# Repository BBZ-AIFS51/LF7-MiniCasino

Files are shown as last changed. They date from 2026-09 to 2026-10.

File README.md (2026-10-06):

<p align="center">
  <picture>
    <source media="(max-width: 600px) and (prefers-color-scheme: dark)" srcset="docs/banner-narrow-dark.svg">
    <source media="(max-width: 600px)" srcset="docs/banner-narrow-light.svg">
    <source media="(prefers-color-scheme: dark)" srcset="docs/banner-dark.svg">
    mini casino: the console with the oled showing the menu, the 4x4 keypad and the rfid tap zone
  </picture>
</p>

a tiny casino on an arduino uno. tap an rfid card, pick black, red or green on the keypad, watch the colours spin on the oled and let the buzzer celebrate. balances live in the uno's eeprom, so the card is just your key.

**[▶ open the 3d model in your browser](https://bbz-aifs51.github.io/LF7-MiniCasino/)**. it plays the game with the real firmware logic, shows every part and wire and has the admin panel built in.

<p align="center">
  <picture>
    <source media="(max-width: 600px) and (prefers-color-scheme: dark)" srcset="docs/how-it-works-narrow-dark.svg">
    <source media="(max-width: 600px)" srcset="docs/how-it-works-narrow-light.svg">
    <source media="(prefers-color-scheme: dark)" srcset="docs/how-it-works-dark.svg">
    how a round works: tap a card, pick a colour, watch the spin, hear the jingle, the balance stays in the eeprom
  </picture>
</p>

## parts

| part | notes |
|---|---|
| arduino uno r3 | atmega328p, usb to the pc, admin protocol at 115200 baud |
| 1.3" oled 128x64 | sh1106 or ssd1306, i2c 0x3c, 4 pins: gnd vcc scl sda |
| rc522 rfid reader | 13.56 mhz, 3.3 v only. any mifare card, fob or ntag works as key |
| 4x4 membrane keypad | 8 pins, no resistors, no gnd. 1 / 2 / 3 bet on black, red, green |
| passive buzzer module + 330 Ω | 3 pins (s, middle, −), plays the jingles |
| half size breadboard, jumpers | 11 female–male, 15 male–male |

## wiring

| part | pin | uno |
|---|---|---|
| oled | gnd / vcc / scl / sda | gnd / 5v / a5 / a4, over the breadboard j2–j5 |
| keypad | 1 / 2 / 3 / 4, columns abcd · 369# · 2580 · 147\* | d3 / d4 / d5 / d6 |
| keypad | 5 / 6 / 7 / 8, rows \*0#d · 789c · 456b · 123a | d7 / d8 / a0 / a1 |
| rc522 | sda / sck / mosi / miso / rst | d10 / d13 / d11 / d12 / d9 |
| rc522 | gnd / 3.3v, irq stays free | gnd / 3.3v, never 5v |
| buzzer | s over 330 Ω, − to the gnd rail | d2 |

keypad pin 1 is the right contact when you look at the keys with the tail down. a2 and a3 are free, d0 and d1 stay free for usb. the breadboard hole by hole is in [UMBAU_OLED.md](UMBAU_OLED.md) and in the picture.

<p align="center">
  <picture>
    <source media="(prefers-color-scheme: dark)" srcset="docs/wiring-dark.svg">
    wiring: uno, breadboard with buzzer and 330 ohm, oled lead in j2 to j5, rc522 and keypad straight to the uno
  </picture>
</p>

<p align="center">
  <picture>
    <source media="(prefers-color-scheme: dark)" srcset="docs/schematic-dark.svg">
    schematic of the mini casino v11
  </picture>
</p>

<p align="center">
  <picture>
    <source media="(prefers-color-scheme: dark)" srcset="docs/pinout-dark.svg">
    uno pinout: which part sits on which pin
  </picture>
</p>

## get it running

1. nothing to install: the oled and rc522 drivers live in the sketch folder.
2. upload `Hardware_Test/Hardware_Test.ino` once to check the oled, the reader and the keypad.
3. open `MiniCasino/MiniCasino.ino`, pick arduino uno and your port, upload.
4. tap a card. new cards get 100 points, then press 1, 2 or 3. a types a new stake, b logs out, c is the volume, d the help.

## the game

* the stake starts at 10 and goes up to 2550 in steps of 10 (key a). black and red pay 2x, green pays 9x. odds are 45 / 45 / 10 %
* a session ends after 60 s without a key press, tap the card again to continue
* up to 31 cards fit into the eeprom, every account keeps two crc protected copies

switches at the top of the sketch: `CASINO_SOUND_MODE` (0 off, 1 passive, 2 active buzzer), `CASINO_EURO` (€ or pkt on the display), `CASINO_OLED_SSD1306` (0 sh1106, 1 ssd1306), `CASINO_SIM` (run without the rc522), `CASINO_NACHLADEN` (refill all accounts once) and `CASINO_EEPROM_LOESCHEN` (wipe everything once).

## extras

* **admin panel**: double click `Panel starten.bat` (or run `python admin/panel.py`) and open http://127.0.0.1:8080. see and edit every balance over usb, ban cards or make one an admin card with unlimited credit. works on a raspberry pi too.
* **no hardware yet?** run `python simulation/build_sim.py` and paste the output into [wokwi](https://wokwi.com). four buttons stand in for the cards. details in [simulation/README.md](simulation/README.md).
* **build check**: `python pruefen.py` compiles for the uno and runs the compile time tests, no upload needed.

## case

a 3d printable console for the whole build, two parts, no supports. stl files, the parametric model and the print notes live in [case/](case/README.md).

**[▶ open the 3d model in your browser](https://bbz-aifs51.github.io/LF7-MiniCasino/)**. the same page lives in the repo as [case/viewer/index.html](case/viewer/index.html) and works offline.

<p align="center">
  case layout: lid top view with oled window, keypad recess, tap zone and grille, plus two sections, in mm
</p>

## more docs (german)

[UMBAU_OLED.md](UMBAU_OLED.md) oled build · [ANLEITUNG.md](ANLEITUNG.md) wiring in detail · [SPIELPLAN_V8.md](SPIELPLAN_V8.md) rules and pins · [SOUND_V9.md](SOUND_V9.md) buzzer · [LOG_ANLEITUNG.md](LOG_ANLEITUNG.md) serial log · [TESTPLAN.md](TESTPLAN.md) test plan

## credits and license

made by **FelixTheDev - Felix Grad** ([felixthedev.com](https://felixthedev.com)) and **derfacn** ([derfacn.com](https://derfacn.com)), lf7 project, bbz aifs51.

licensed under the [Mini Casino Attribution License](LICENSE): you may use, copy and change everything, but every copy, fork or public use has to credit FelixTheDev - Felix Grad and derfacn visibly and link [felixthedev.com](https://felixthedev.com) and [derfacn.com](https://derfacn.com).

 the graphics and the schematic are generated by `docs/make_graphics.py` straight from the firmware and the case model.

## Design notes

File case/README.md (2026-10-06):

# case

a 3d printable console for the V11 build. two parts, a body and a lid, everything else screws, clips or sticks onto them. the lid is tilted by 10°: the oled sits behind a chamfered window right above the keypad, the rfid tap zone and the buzzer grille are on the right, the usb-b cable leaves at the back.

**[open the interactive model](https://bbz-aifs51.github.io/LF7-MiniCasino/)** on github pages, or open [viewer/index.html](viewer/index.html) straight from the folder, no server needed. it shows this case with every part and wire inside and plays the game like the firmware.

the page on github pages comes from the `gh-pages` branch. after changing the viewer, publish it again with

```bash
git subtree push --prefix case/viewer origin gh-pages
```

<p align="center">
  case layout: lid top view and two sections, all dimensions in mm
</p>

## what goes where

| part | where | how it is held |
|---|---|---|
| arduino uno | back left, usb-b and dc jack through the back wall | four standoffs, 4 × m3 × 6 self tapping |
| half breadboard | back right, the ky-006 buzzer (c26–c28) stands right under the grille | shallow pocket, its own adhesive |
| 1.3" oled | lid, behind the window above the keypad, header to the back | flush under the lid in a frame with 2 snap clips, 4 × m2 optional |
| 4x4 keypad | lid, in a 0.8 mm recess so the membrane ends flush | its adhesive, tail through the slot at the front edge |
| rc522 | lid, under the tap zone, component side down | 4 pegs in its holes, 2 snap clips, 90° header toward the centre |

wires: oled lead to j2–j5, rc522 straight to the uno with 7 wires, keypad with 8 jumpers to d3–d8, a0, a1. all hole by hole in [UMBAU_OLED.md](../UMBAU_OLED.md).

## files

| file | what |
|---|---|
| `stl/base.stl` | the body, print as is |
| `stl/lid.stl` | the lid, already flipped for printing (face down) |
| `stl/assembly.stl` | both in place, just for looking at |
| `stl/fitcheck/` | dummy oled, keypad, rc522, uno, breadboard and buzzer, in place, with headers and dupont housings. load them with `assembly.stl` to check the fit in your slicer |
| `make_case.py` | the model itself, every number is a named parameter with its source |
| `dims.json` | the key numbers, the lid features and the last fit check, written by the script |
| `layout.svg` | the dimensioned drawing above, light and dark |
| `viewer/data/case_geo.js` | the meshes and part positions for the viewer, written by the script (about 280 kb) |

## numbers

| | mm |
|---|---|
| footprint | 200 × 148 |
| height front / back | 34 / 60.1 |
| walls / floor / lid | 2.4 / 3 / 3 |
| corners | r 10 in plan, r 1.8 on the lid edge, 0.4 chamfers at the lid joint |
| oled window | 30.2 × 15.5 at the panel, 45° chamfer to 31.8 × 17.1, panel 1.2 below the top |
| keypad recess | 69.6 × 77.3, 0.8 deep, ribbon slot 22 × 3.8 (the 8 pin connector passes) |
| tap zone | engraved ring ø52 and contactless mark, lid thinned to 1.6 over the antenna |
| buzzer grille | 37 × ø1.8 in four rings |
| lid screws | 4 × m3 × 12 countersunk into corner bosses, holes 2.7 for self tapping (4.0 for heat set inserts) |
| back wall | usb-b 13.2 × 12.2, dc jack ø11.5, both chamfered |
| uno standoffs | 5 high, clear the pin ends under the board |
| breadboard pocket | 83.3 × 55.3 × 0.6 |
| rubber feet | 4 × ø10.5 recesses, 0.8 deep |

the lid is laid out on a grid: keypad and oled on one axis 54.8 from the left edge, tap zone and grille on the mirrored axis, the keypad and the tap zone share one row, the window and the grille the other. margins are 20 to the keypad on the sides and the front.

## fit check

`make_case.py` ends with an automatic check. every dummy part, every dupont housing and the room each wire needs to bend (6.5 behind the housing) is tested against the body, the lid and the other parts. any overlap stops the script with an error. the last run:

| part | resting on | smallest gap to the case | wire bends |
|---|---|---|---|
| uno | standoffs | 0.38, usb-b corner in its opening | 5.7 to the lid |
| breadboard | pocket floor | 8.5 | 12.5 |
| buzzer | breadboard | 8.5 | |
| oled | lid underside | 0.1, panel under the window | 8.7 |
| rc522 | lid underside | 0.2 | 1.6 |
| keypad | recess floor | 0.8, tail in the slot | |

there is room for 14 mm dupont housings plus the bend above the uno headers and the breadboard everywhere under the lid.

## printing

* pla or petg, 0.2 mm layers, 3 walls, 15 % infill, no supports on either part
* body open side up. lid as exported, top face on the bed: the bed gives the top its finish, the window chamfer, the countersinks and the engravings print as 45° overhangs or tiny bridges
* the keypad recess floor is one wide bridge on the first layers. it ends up under the keypad, slow bridges keep it flat
* roughly 260 g and 12 to 14 h for both parts with a 0.4 mm nozzle

## assembly

1. print body and lid
2. uno onto the four standoffs with m3 × 6 screws, usb-b and the dc jack line up with the back wall
3. breadboard into its pocket. buzzer s / middle / − into c26 / c27 / c28, 330 Ω from e24 to e26, a24 to d2, e28 to the lower inner rail, rail to gnd
4. keypad: feed the connector through the slot first, then stick the keypad into the recess. 8 jumpers to d3, d4, d5, d6, d7, d8, a0, a1
5. oled from below into its frame, glass up into the window, it snaps in. 4 wire lead to j2–j5, then f2 gnd, g3 5v, h4 a5, i5 a4
6. rc522 component side down onto the pegs under the tap zone until both clips catch, pin ends on the back no longer than 1.5. 7 wires straight to the uno, 3.3 v only
7. lid on, 4 × m3 × 12 countersunk, rubber feet into the recesses underneath. usb in, upload `MiniCasino.ino`, tap a card

## changing it

```bash
pip install manifold3d numpy
python case/make_case.py
```

all sizes and positions are in the parameter block at the top of `make_case.py`. lid features use lid coordinates: u across, v up the slope from the front edge. the script rewrites the stl files, `dims.json`, `layout.svg` and the viewer geometry, so the 3d model shows the change right away.

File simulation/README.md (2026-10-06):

# Simulation mit Wokwi

Der komplette Automat im Browser, ohne jede Hardware: OLED, Tastatur, Buzzer
und der EEPROM mit allen Konten. **[wokwi.com](https://wokwi.com)** aufrufen,
*New Project* → *Arduino Uno*.

## Der Kartenleser

Wokwi hat **kein RFID-Modul** im Teilekatalog — den RC522 kann man dort nicht
nachbauen. Das fällt aber kaum ins Gewicht, weil die Karte seit V10 nur noch
ihre UID liefert; der Kartenspeicher wird gar nicht mehr gelesen.

Ersatz sind **vier Taster an D9 bis D12**, also genau den Pins, an denen sonst
der Reader hängt. Jeder steht fest für eine Karte:

| Taster | UID | Typ |
|---|---|---|
| Karte 1 | `DF51AA39` | MIFARE Classic, 4 Byte |
| Karte 2 | `0885B1A8` | MIFARE Classic, 4 Byte |
| Karte 3 | `049F905C110189` | Ultralight, 7 Byte |
| Karte 4 | `04CABD5C110189` | Ultralight, 7 Byte |

Drücken heißt auflegen. Der Sketch geht denselben Weg wie nach einem echten
Scan: Konto suchen, unbekannte UID anlegen und aufladen, Sitzung starten.

Wer mehr als vier Spieler braucht, nimmt den seriellen Monitor:

```
CARD 11223344
```

Jede Hexfolge mit 8, 14 oder 20 Zeichen gilt als UID. Auch alle anderen
Verwaltungsbefehle funktionieren dort (`PING`, `LIST`, `SET`, `STAKE`, `FLAG`,
`FREE`, `SOUND`, `WIPE JA`) — Übersicht in
[AdminSerial.h](../MiniCasino/AdminSerial.h). Das Web-Adminpanel läuft **nicht**
mit Wokwi: es braucht eine echte serielle Schnittstelle.

## Einrichten

```bash
python simulation/build_sim.py
```

Das erzeugt `simulation/wokwi/` mit den Dateien für Wokwi. In Wokwi dann:

1. Inhalt von **`sketch.ino`** in den vorhandenen Reiter *sketch.ino* kopieren
   (eine Zeile — der Rest steckt in `casino.h`).
2. Inhalt von **`diagram.json`** in den vorhandenen Reiter *diagram.json*.
3. Über das **+** eine neue Datei **`casino.h`** anlegen und befüllen.
4. **Start** drücken, unten den seriellen Monitor aufklappen.

Bibliotheken braucht es keine: Display- und RFID-Treiber stecken in
`casino.h`, `EEPROM` bringt Wokwi mit. Wokwi kennt nur den OLED-Chip
SSD1306; in der Simulation wird er deshalb automatisch benutzt.

Warum die Umleitung über `casino.h`: die Arduino-Toolchain setzt automatisch
Funktionsprototypen an den Anfang jeder `.ino`, also noch vor die eingebetteten
Enums — das übersetzt nicht. Steht in der `.ino` nur ein `#include`, gibt es
nichts zu ergänzen.

**Der Sketch in `MiniCasino/` bleibt die einzige Quelle.** `build_sim.py` fügt
nur zusammen und schaltet `CASINO_SIM` ein. Nach jeder Änderung am Projekt das
Skript erneut laufen lassen und `casino.h` in Wokwi ersetzen.

## Verdrahtung

| Bauteil | Anschluss |
|---|---|
| OLED GND / VCC / SCL / SDA | GND / 5 V / A5 / A4 |
| Tastatur R1–R4 / C1–C4 | A1, A0, D8, D7 / D6, D5, D4, D3 |
| Buzzer | D2 gegen GND |
| Karte 1–4 (nur Simulation) | D9 / D10 / D11 / D12 gegen GND |

Die Tastatur braucht keine Widerstände, der Sketch nutzt `INPUT_PULLUP`.

Am echten Aufbau kommt statt der Kartentaster der RC522 an dieselben Pins:
SDA→D10, RST→D9, MOSI→D11, MISO→D12, SCK→D13, VCC→**3,3 V** (nicht 5 V),
GND→GND. Dann `CASINO_SIM` in `MiniCasino.ino` wieder auf `0`.

## Bedienung

1. **Karte 1** drücken → `100€` Startguthaben, OLED zeigt `10€ 1S 2R 3G`
2. Auf der Tastatur 1 (Schwarz), 2 (Rot) oder 3 (Grün) tippen → Lauflicht, Ergebnis, neuer Stand
3. **1 halten** → Einsatz einstellen
4. **2 halten** → Logout · **3 halten** → Ton laut/leise/aus

## Was sich gut ausprobieren lässt

- Spielablauf, Auszahlungen und die Chancen über viele Runden
- Einsatz einstellen, Sitzungsablauf nach 60 Sekunden, Logout
- Sperren und Adminkarten über `FLAG`
- Wie sich der EEPROM füllt — bis 31 Karten, danach `UID-Liste voll`

Nicht simulierbar ist alles rund um die Funkstrecke: Reichweite,
Erkennungsfehler, Versorgungseinbrüche. Dafür braucht es echte Hardware.

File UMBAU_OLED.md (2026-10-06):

# Umbau V11: OLED statt LCD, Tastatur statt Taster, keine LEDs

Das 16x2-LCD ist durch ein **1,3"-OLED mit I2C** (4 Pins) ersetzt. Die drei LEDs sind
weggefallen: Das Lauflicht läuft jetzt auf dem Display. Statt drei Tastern gibt es
eine **4×4-Folientastatur** mit 8 Pins. Spiel, Konten, Buzzer und RC522 bleiben
unverändert.

Vor dem Umstecken immer USB abziehen.

## Pinbelegung

| Uno | Funktion |
|---|---|
| D0/D1 | USB-Seriell, nicht belegen |
| D2 | Buzzer über 330 Ω |
| D3–D6 | Tastatur Pin 1–4, die Spalten von rechts nach links |
| D7, D8 | Tastatur Pin 5, 6, die Reihen `* 0 # D` und `7 8 9 C` |
| D9–D13 | RC522 |
| A0, A1 | Tastatur Pin 7, 8, die Reihen `4 5 6 B` und `1 2 3 A` |
| A2, A3 | frei |
| A4 | OLED SDA |
| A5 | OLED SCL |

## Breadboard, Loch für Loch

Spalten 1–30, Reihen a–e oben und f–j unten. Eine Spalte mit 5 Löchern ist intern
verbunden. Wenn euer Breadboard anders nummeriert ist, zählen nur die Abstände.
Die untere innere Schiene ist **GND**, die anderen Schienen bleiben frei.

### OLED

Die Pins kommen in **j2 bis j5**: GND, VCC, SCL, SDA. Prüft die Reihenfolge auf
eurem Modul, manche haben VCC und GND vertauscht.

| von | zu |
|---|---|
| f2 | GND |
| g3 | 5V |
| h4 | A5 |
| i5 | A4 |

### Tastatur

Die drei Taster und ihre Kabel kommen raus. Die Tastatur braucht weder Breadboard
noch GND noch Widerstände: 8 Kabel der Reihe nach direkt vom Stecker zum Uno.

| Tastatur-Pin | Uno | Leitung |
|---|---|---|
| 1 | D3 | Spalte `A B C D` |
| 2 | D4 | Spalte `3 6 9 #` |
| 3 | D5 | Spalte `2 5 8 0` |
| 4 | D6 | Spalte `1 4 7 *` |
| 5 | D7 | Reihe `* 0 # D` |
| 6 | D8 | Reihe `7 8 9 C` |
| 7 | A0 | Reihe `4 5 6 B` |
| 8 | A1 | Reihe `1 2 3 A` |

So steht es in `GameRuntime.h`: `KEYPAD_REIHEN = {A1, A0, 8, 7}` und
`KEYPAD_SPALTEN = {6, 5, 4, 3}`. D3–D6 sind also die Spalten von rechts nach
links, D7, D8, A0 und A1 die Reihen von unten nach oben. Schaut man von vorne
auf die Tasten, Folienschwanz unten, ist Pin 1 der rechte Kontakt und Pin 8 der
linke. Die Firmware fragt immer eine Reihe nach der anderen ab, die Spalten
lesen über die internen Pullups mit. Was jede Taste tut, steht unten unter
Bedienung.

Der Code ist auf euren Aufbau eingestellt und dort mit allen 16 Tasten getestet.
Steckt jemand den Stecker andersherum, zeigt `Hardware_Test` bei der 1 ein `D` an.
Dann in `GameRuntime.h` die Zeilen `KEYPAD_REIHEN` und `KEYPAD_SPALTEN`
tauschen, siehe Kommentar dort.

### Buzzer

- Der Buzzer steckt in **c26** (S), **c27** (Mitte, bleibt frei) und **c28** (−).
- Der 330-Ω-Widerstand geht von **e24 nach e26**.
- Ein Kabel geht von **a24 zu D2**.
- Ein Kabel geht von **e28 zur GND-Schiene**.

### Masse

Ein Kabel von der GND-Schiene zum **GND** am Arduino. Die Schiene braucht jetzt
nur noch der Buzzer.

### RC522

Der RC522 hängt direkt am Uno, mit 7 Kabeln:

| RC522 | Uno |
|---|---|
| SDA | D10 |
| SCK | D13 |
| MOSI | D11 |
| MISO | D12 |
| IRQ | frei |
| GND | GND |
| RST | D9 |
| 3.3V | 3.3V, nicht 5V |

Alle Teile müssen dieselbe Masse haben: Uno, OLED, Buzzer und RC522.

## Software

Es muss **keine Bibliothek** installiert werden. Display-Treiber, Schrift und
RC522-Treiber liegen im Sketch-Ordner (`OledText.h`, `Rc522.h`).

1. Zuerst **`Hardware_Test/Hardware_Test.ino`** hochladen und den seriellen Monitor
   auf 115200 Baud stellen:
   - `I2C-Geraet auf 0x3C`: das OLED antwortet. Steht dort `Kein I2C-Geraet`,
     sind SDA/SCL vertauscht oder VCC/GND fehlen.
   - `RC522 Version 0x88` (Originale: `0x91`/`0x92`): der Reader antwortet. Bei
     `0x00` oder `0xFF` stimmt ein Kabel nicht, oft sind MOSI und MISO vertauscht.
   - Jede gedrückte Taste erscheint als `Taste: 1` usw. Kommt bei der 1 ein `D`,
     steckt der Stecker andersherum (siehe Abschnitt Tastatur).
2. Danach `MiniCasino/MiniCasino.ino` hochladen. Ist das Bild um zwei Pixel
   verschoben oder steht am Rand Pixelmüll, `CASINO_OLED_SSD1306` auf `1` setzen.

Das OLED zeigt oben einen festen Balken `MINI CASINO`, darunter zwei große
Textzeilen und ganz unten eine kleine Hinweiszeile mit den Tasten, die gerade
gelten.

## Bedienung

| Taste | Funktion |
|---|---|
| 1 / 2 / 3 | auf Schwarz / Rot / Grün setzen |
| A | Einsatz eintippen: Ziffern, `#` = OK, `*` = letzte Ziffer löschen bzw. abbrechen |
| B | Abmelden, mit Rückfrage (`#` = ja, `*` = nein) |
| C | Ton laut / leise / aus |
| D | Hilfe, blättert durch drei Seiten |

Der Einsatz muss mindestens 10, ein Vielfaches von 10 und höchstens so hoch wie
das Guthaben sein (maximal 2550). Das Display zeigt die Obergrenze gleich mit an.
Ohne Tastendruck geht jede Eingabe nach 20 Sekunden zurück ins Menü, nach
60 Sekunden endet die Sitzung.

## Speicher

Der Sketch belegt rund **18 KB** von den 28 KB, die neben dem großen Bootloader
eures Uno frei sind, und rund 520 Byte RAM. Gespart wurde durch eigene kleine
Treiber statt Bibliotheken:

| Was | gespart |
|---|---|
| eigener OLED-Treiber statt U8g2 und Wire | rund 5 KB Flash, 280 Byte RAM |
| eigener RC522-Treiber statt MFRC522 | rund 1,5 KB |
| Buzzer von Hand getaktet statt `tone()` | rund 1,6 KB |
| Admin-Protokoll ohne `strtoul`/`atoi`, kürzere Texte | rund 1,1 KB |
| eigener Zufallsgenerator statt `random()` | rund 0,3 KB |

`DEBUG_LOG` steht weiter auf `false`. Damit werden die Diagnose-Texte gar nicht
erst mitkompiliert. Mit `true` wären es rund 21 KB, das passt inzwischen auch.

## Gehäuse, 3D-Viewer und Grafiken

Alles zeigt jetzt den Aufbau V11:

- Das Gehäuse in `case/` hat das Fenster für das OLED, die Mulde für die
  Tastatur mit dem Schlitz für das Flachkabel und die Tap-Zone über dem RC522.
  LCD-Ausschnitt, LED- und Tasterlöcher sind weg.
- Der 3D-Viewer in `case/viewer/` zeigt dieselben Teile und Kabel und spielt
  mit der Logik der Firmware.
- Schaltplan, Verdrahtung, Pinbelegung und die Bilder im README erzeugt
  `python docs/make_graphics.py` direkt aus der Firmware (Schrift, Tastatur,
  Spieltakt) und den Kabeln in `case/viewer/js/core.js`.

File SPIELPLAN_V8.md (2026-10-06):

# Mini Casino V8 – Lauflicht und seltenes Grün

**Ergänzung V9:** Die Spielregeln und Pins hier gelten weiter. Ton ist jetzt
im Hauptsketch eingeschaltet. Für den aktuellen Anschluss und Modus gilt
[SOUND_V9.md](SOUND_V9.md); die frühere Angabe „deaktiviert“ weiter unten ist überholt.

## Spiel und Animation

Eine Taste wählt Schwarz, Rot oder Grün und setzt 10 Punkte. Die neue Ziehung
verwendet 100 mögliche Lose:

| Farbe | Lose | Chance | Auszahlung bei Treffer |
|---|---|---|---|
| Schwarz | 0–44 | 45 % | 20 Punkte |
| Rot | 45–89 | 45 % | 20 Punkte |
| Grün | 90–99 | 10 % | 90 Punkte |

Grün ist seltener und zahlt den neunfachen Einsatz aus. Bei 100 Punkten führt
ein Treffer auf Schwarz/Rot zu 110, ein Treffer auf Grün zu 180 und eine
Niederlage zu 90. Die Auszahlung enthält den zuvor abgezogenen Einsatz:
Grün bedeutet also 80 Punkte Nettogewinn, Schwarz/Rot je 10 Punkte.
Unter 10 Punkten startet keine Runde.
Die Auszahlungen sind auf denselben durchschnittlichen Rückfluss abgestimmt:
45 % × 20 = 10 % × 90 = 9 Punkte je 10 Punkte Einsatz.
Die Prozente beschreiben die vorgesehene Zufallsverteilung; kurze Serien können
stark davon abweichen.

Die LED-Reihenfolge lautet Schwarz → Rot → Grün → Schwarz. Das Lauflicht
beginnt an einer zufälligen Position, läuft 24–26 Schritte und bremst von
45 auf 500 Millisekunden pro Schritt ab. Es dauert ungefähr fünf Sekunden.
Die letzte LED entspricht immer dem bereits gezogenen Ergebnis. Sie bleibt
an, bis eine neue Runde beginnt oder eine Karte neu eingelesen wird.
Es leuchtet immer höchstens eine LED. Ein neues Ergebnis wird während des
Lauflichts nicht gezogen; zusätzliche Tastendrücke werden nicht angenommen.

## Drei einzelne LEDs anschließen (bis V10, überholt)

**Ab V11 gibt es keine LEDs mehr, das Lauflicht läuft auf dem OLED. Siehe [UMBAU_OLED.md](UMBAU_OLED.md).**

Diese Verdrahtung gilt für gewöhnliche **zweibeinige Einzel-LEDs**.
Vor dem Umstecken USB/Strom trennen. Jede LED braucht einen eigenen
**330-Ohm-Vorwiderstand**. Den vorhandenen LCD-Widerstand unverändert lassen.

| Anzeige | Anschluss |
|---|---|
| LED für Schwarz | A3 → 330 Ω → Anode (+); Kathode (−) → GND |
| LED für Rot | A4 → 330 Ω → Anode (+); Kathode (−) → GND |
| LED für Grün | A5 → 330 Ω → Anode (+); Kathode (−) → GND |

```text
Uno A3 ──[330 Ω]── Anode  LED „Schwarz“  Kathode ── GND
Uno A4 ──[330 Ω]── Anode  LED Rot        Kathode ── GND
Uno A5 ──[330 Ω]── Anode  LED Grün       Kathode ── GND
```

Bei üblichen neuen LEDs ist das lange Bein die Anode; das kurze Bein und die
abgeflachte Gehäuseseite kennzeichnen normalerweise die Kathode. Bei gekürzten
Beinen die Kennzeichnung beziehungsweise einen Diodentest verwenden.
Für das Feld Schwarz könnt ihr beispielsweise eine weiße oder gelbe LED benutzen;
die Zuordnung wird durch A3 festgelegt. Eine „schwarz leuchtende LED“ braucht ihr nicht.

Nicht alle drei LEDs an einen gemeinsamen Widerstand anschließen. Die Kathoden
dürfen sich dieselbe GND-Schiene teilen. Diese Schiene mit Arduino GND und den
bisherigen GND-Schienen verbinden. Drei LEDs bedeuten nicht drei separate GND-Pins.
Das grundsätzliche Prinzip LED plus Vorwiderstand zeigt auch
[Arduinos Blink-Beispiel](https://docs.arduino.cc/built-in-examples/basics/Blink/).

Falls eure LEDs mehr als zwei Pins oder bereits eine Modulplatine haben, gilt
diese Pinbelegung nicht automatisch; dann zuerst deren Beschriftung prüfen.

## Vollständige Uno-Belegung (bis V10, überholt)

| Uno-Pins | Funktion |
|---|---|
| D0/D1 | USB-Seriell und Upload; keine zusätzliche Beschaltung |
| D2 | Speaker-/Buzzer-Signal reserviert, weiterhin deaktiviert |
| D3–D8 | LCD wie bisher |
| D9–D13 | RC522 wie bisher |
| A0 | Schwarze Schließertaste nach GND, INPUT_PULLUP |
| A1 | Rote Schließertaste nach GND, INPUT_PULLUP |
| A2 | Grüne Schließertaste nach GND, INPUT_PULLUP |
| A3 | LED für Schwarz über eigenen 330-Ω-Widerstand |
| A4 | Rote LED über eigenen 330-Ω-Widerstand |
| A5 | Grüne LED über eigenen 330-Ω-Widerstand |

**Der Aufbau passt genau auf den Uno.** Mit dem reservierten Ton-Ausgang sind
jetzt alle zusätzlichen Ein-/Ausgänge verplant. A4/A5 stehen deshalb nicht
gleichzeitig für ein weiteres I2C-Gerät zur Verfügung. Für spätere Erweiterungen
müsste man Pins neu aufteilen oder zusätzliche Hardware nutzen; für V8 ist das
nicht nötig.

A3 ist nun ein LED-Ausgang. Die bisherige Zufallsstartwert-Abfrage über
`analogRead(A3)` wurde vollständig entfernt. Der Pseudozufallszustand wird mit
dem Zeitpunkt des Tastendrucks gemischt. Dieser Generator ist nicht für einen
manipulationssicheren Echtgeldbetrieb ausgelegt.

Der 3-Pin-Speaker bleibt unverbunden, bis Modell, Pinbeschriftung und passende
Versorgung feststehen. D2 bleibt frei von LEDs, damit sein geplanter Anschluss
möglich bleibt. `CASINO_SOUND_MODE` ist weiterhin 0.

## Ablauf und Guthabenschutz

1. Karte auflegen und liegen lassen; Farbtaste kurz drücken.
2. Guthaben und UID frisch prüfen. Ohne mindestens 10 Punkte kein Spiel.
3. Ergebnis einmalig gewichtet ziehen.
4. Einsatz und festes Ergebnis als offene Runde auf der Karte speichern und
   zurücklesen; anschließend den endgültigen Kartenstand speichern und prüfen.
5. **Erst nach bestätigter Buchung** das Lauflicht abspielen und auf dem
   gezogenen Ergebnis anhalten. Anschließend zeigt das LCD Gewinn/Verlust und Guthaben.

Damit findet während des Lauflichts keine Guthabenbuchung statt. Ein Reset
während der Animation macht die bereits bestätigte Buchung nicht rückgängig
und erzeugt auch keine zweite Auszahlung. Die Animation wird nach Reset nicht
nachträglich abgespielt; die Karte enthält ihren fertigen Endstand.

Schlägt das Schreiben davor fehl, erscheint Runde offen. Dieselbe Karte erneut
auflegen oder eine Taste drücken setzt den bestehenden Vorgang fort, ohne neue
Ziehung oder zusätzlichen Einsatz. Eine gültige offene Runde überlebt auch
einen Neustart. Eine beschädigte Mehrseiten-Schreibung zusammen mit Stromausfall
kann dagegen weiterhin nicht automatisch wiederhergestellt werden. Diese Grenze
der Kartenspeicherung bleibt bestehen.

V6-/V7-Guthaben und die einmalige Aufladung pro UID bleiben kompatibel. Die
EEPROM-Liste bleibt unverändert. Abgeschlossene Guthaben behalten MCAS-Version 1.
Neue offene Runden verwenden MCAS-Version 3 und speichern in Byte 13 zusätzlich
den Auszahlungsfaktor: 2 bei Schwarz/Rot, 9 bei Grün. Die übrigen Felder stimmen
mit der offenen Version 2 überein; der Faktor gehört zur CRC-Prüfung.
Beim Fortsetzen wird dieser gespeicherte Faktor verwendet.

Eine noch offene V7-Runde (Kartenformat Version 2) behält das bisherige Ergebnis
und die bisherige Auszahlung von 20 Punkten auch für Grün. Nur neue Runden
verwenden 45/45/10 und die höhere Grün-Auszahlung. V7 kann neue offene
Version-3-Runden nicht fortsetzen; dafür V8 benutzen.

## Installation, Dateien und Prüfung

Den vollständigen Ordner MiniCasino mit allen sieben Dateien übernehmen und
MiniCasino.ino auf den Uno laden. Monitor bei Bedarf auf **115200 Baud** stellen;
BOOT muss **Mini Casino v8** zeigen. Die bestehenden Bibliotheken bleiben gleich.

Die Chancen und die Berechnung des Lauflichts stehen in `GameRules.h`, die
LED-Pins und Ausgabe in `GameRuntime.h`. Die übrigen Dateien bleiben zuständig
für RFID, Kartenformat, Tasten und UID-Merkliste. LCD-/RFID-Anschlüsse stehen in
[ANLEITUNG.md](ANLEITUNG.md), die Merkliste in [UidRegistry.h](MiniCasino/UidRegistry.h).

Lokal geprüft: Uno kompiliert und gelinkt; alle bisherigen Logikprüfungen plus
sämtliche 100 Lose und alle neun Kombinationen aus Start- und Zielfarbe des
Lauflichts. Die Tests prüfen auch zunehmende Verzögerungen und das passende
letzte Licht ohne nachträglichen Sprung. Zusätzlich werden die 90-Punkte-Auszahlung,
Überlaufgrenzen und die unveränderte Auszahlung alter offener Runden geprüft.
Programm: 20.172 Byte, statischer RAM:
465 Byte. Der neue LED-Aufbau wurde nicht am realen Arduino getestet.

Am Aufbau prüfen: LED-Polarität, passende LED zum LCD-Ergebnis, Gedrückthalten
ohne Folgerunden, Guthaben nach Gewinn/Verlust und unveränderten Stand nach Reset.

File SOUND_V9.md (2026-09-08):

# Ton im Hauptprogramm V9

Öffnet `MiniCasino/MiniCasino.ino` in der Arduino IDE und ladet diesen Sketch
auf den Uno. Alle sieben Header bleiben im selben Ordner. Es gibt keinen
zusätzlichen Ton-Sketch zum Einfügen und kein ZIP-Archiv.

## Anschluss

| Modul | Uno |
|---|---|
| S | D2 über einen 330-Ω-Widerstand |
| − | GND |
| Unbekannter mittlerer Pin | Offen lassen |

D2 war für Ton reserviert. LCD, RFID, Taster und LEDs behalten ihre Pins.
Die Beschriftung S/− allein identifiziert euer Modul nicht eindeutig. Dieser
vorsichtige Anschluss eignet sich zum Versuch mit einem einfachen Buzzer-Modul;
ob ein anderes Modul zusätzliche Versorgung braucht, lässt sich erst anhand
seines Typs feststellen. Den unbekannten mittleren Pin nicht auf Verdacht speisen.

## Einstellung direkt in der Hauptdatei

Oben in `MiniCasino.ino` steht bereits:

```cpp
#define CASINO_SOUND_MODE 1
```

| Wert | Funktion |
|---|---|
| 1 – Standard, eingeschaltet | Passiver Buzzer: verschiedene Tonhöhen und Melodien |
| 2 | Aktiver Buzzer: gleicher Rhythmus mit seiner festen Tonhöhe |
| 0 | Ton aus |

Ein aktiver Buzzer kann die Melodie nicht nachspielen. Einfache Buzzer geben
keine MP3s oder gesprochenen Meme-Samples wieder; dafür wäre ein Audioplayer
mit geeignetem Lautsprecher nötig. Die eingebauten Sounds sind eigene kurze
Tonfolgen im 8-Bit-/Meme-Stil.

## Wann welcher Sound läuft

| Ereignis | Sound |
|---|---|
| Jeder LED-Wechsel | Kurzer Tick; wird zusammen mit dem Lauflicht langsamer |
| Gewinn auf Schwarz oder Rot | Aufsteigender Level-up-Jingle |
| Verlust | Absteigendes Womp-womp |
| Auf Grün gesetzt und Grün getroffen | Längere Jackpot-Fanfare, LCD zeigt JACKPOT! GRUEN |

Ein grünes Ergebnis bei einer falschen Farbwahl ist ein Verlust und löst keinen
Jackpot aus. Auszahlung bleibt Schwarz/Rot 20, Grün 90 bei 10 Punkten Einsatz.
Der Jackpot bringt daher netto 80 Punkte. Es gibt keinen zusätzlichen Jackpot-Topf.

Die Tonfolgen stehen in `GameSounds.h` im Flash, die Wiedergabe in
`GameRuntime.h`. Einsatz und Auszahlung werden vor Lauflicht und Jingle
gespeichert und bestätigt. Während der kurzen Tonfolge werden keine weiteren
Runden gestartet; anschließend müssen die Tasten erst losgelassen werden.
Jeder Ergebnis-Jingle dauert höchstens drei Sekunden.

Im optionalen seriellen Monitor mit 115200 Baud erscheint `SOUND` mit WIN,
LOSS oder JACKPOT. Bei Tonmodus 0 entfällt diese Ausgabe. Die Funktion `tone()`
verwendet beim Uno Timer 2; LCD-Digitalausgänge und die SPI-Verbindung laufen
weiter. PWM per `analogWrite()` auf D3/D11 wird in diesem Projekt nicht verwendet.

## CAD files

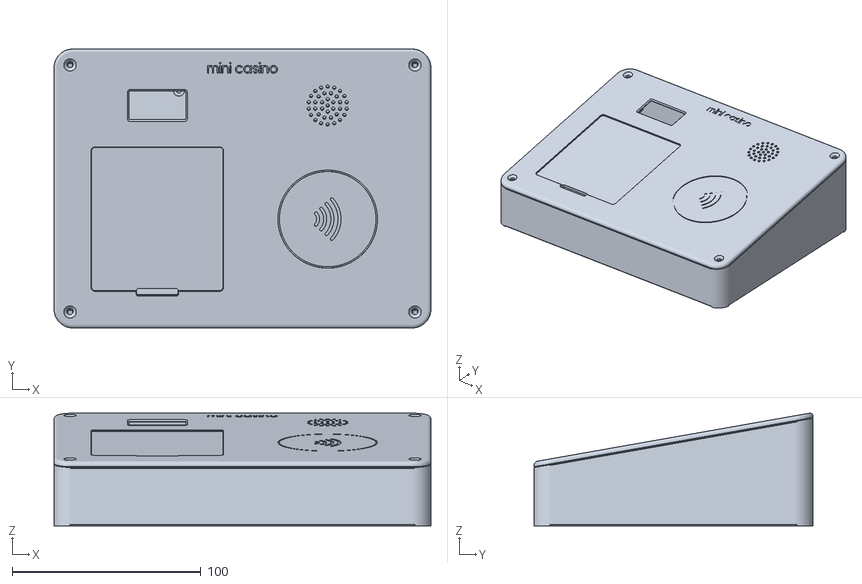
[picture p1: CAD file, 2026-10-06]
case/stl/assembly.stl
200.0 x 148.0 x 59.8

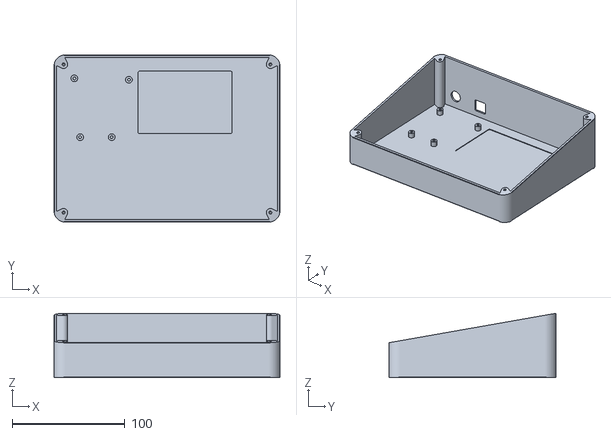
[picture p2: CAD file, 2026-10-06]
case/stl/base.stl
200.0 x 148.0 x 57.0

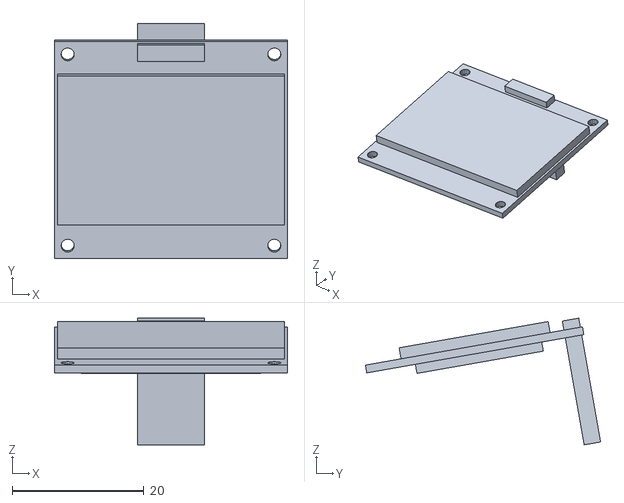
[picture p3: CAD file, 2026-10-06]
case/stl/fitcheck/oled.stl
35.4 x 35.7 x 19.3

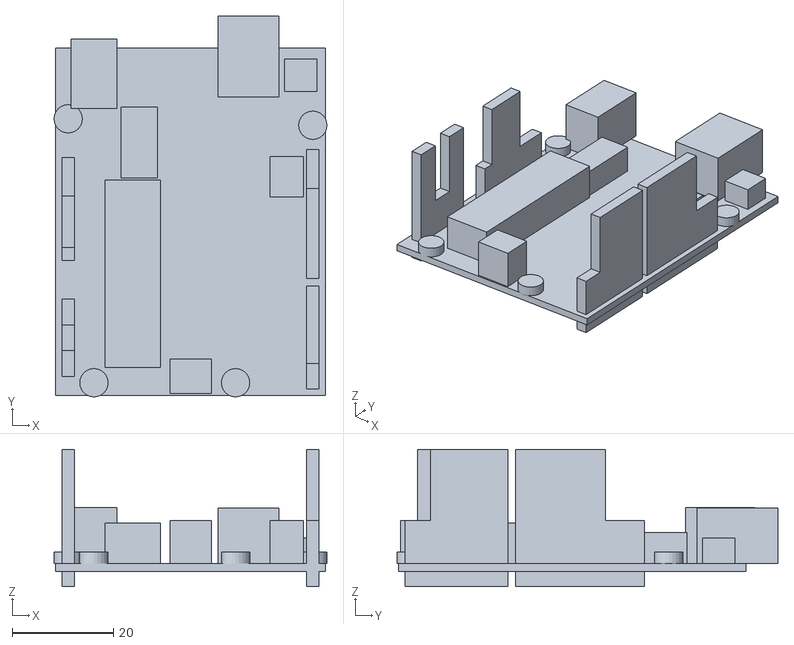
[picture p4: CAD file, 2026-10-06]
case/stl/fitcheck/uno.stl
53.9 x 75.1 x 27.1

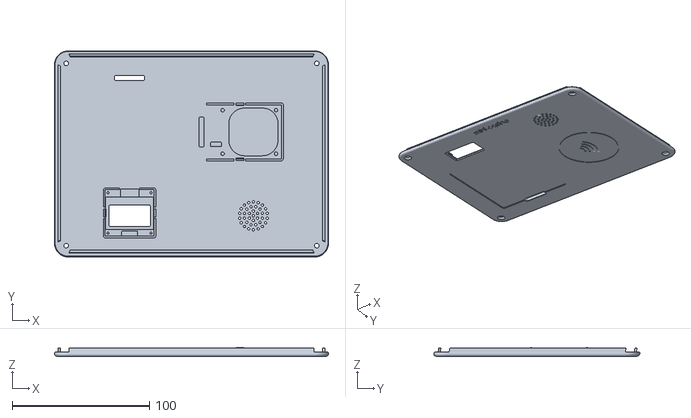
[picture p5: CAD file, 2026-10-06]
case/stl/lid.stl
200.0 x 150.4 x 6.25

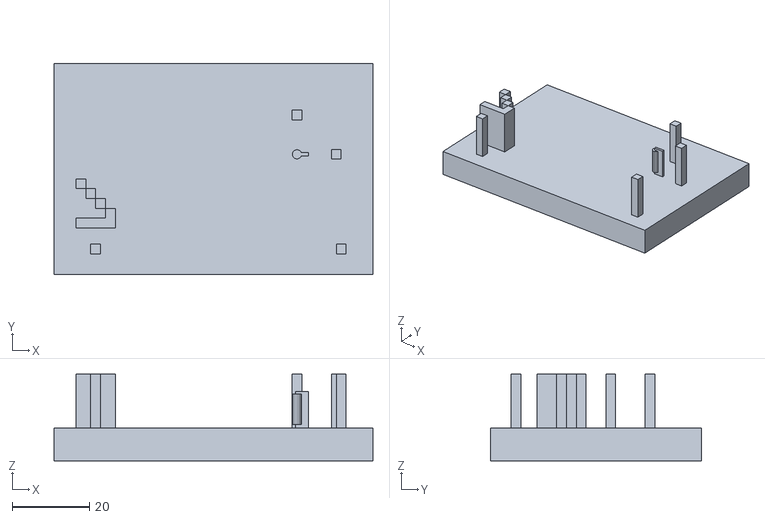
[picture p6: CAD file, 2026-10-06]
case/stl/fitcheck/breadboard.stl
82.5 x 54.5 x 22.5

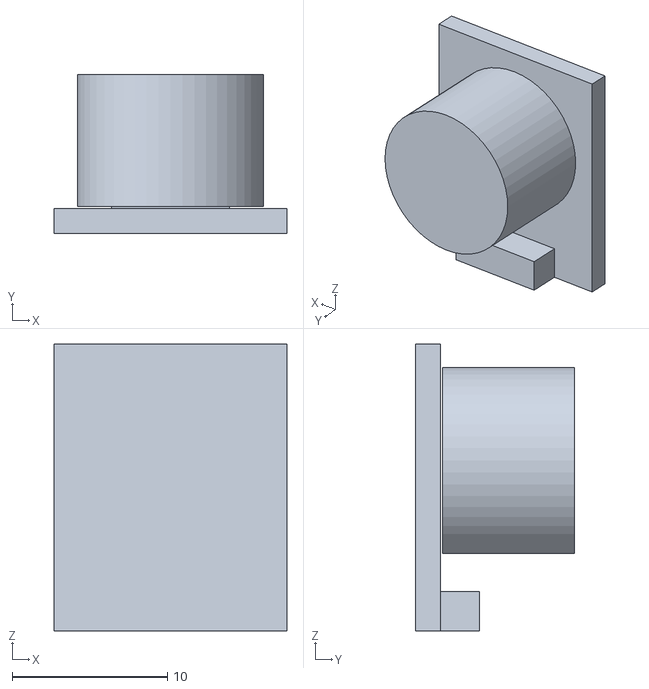
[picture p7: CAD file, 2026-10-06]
case/stl/fitcheck/buzzer.stl
15.0 x 10.2 x 18.5

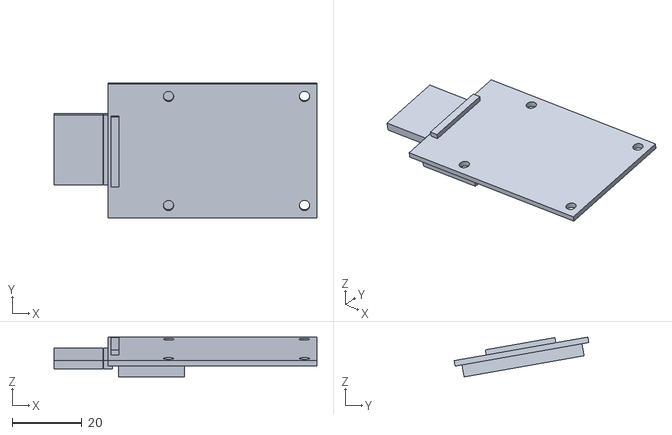
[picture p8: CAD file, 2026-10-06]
case/stl/fitcheck/rc522.stl
75.5 x 38.7 x 11.4

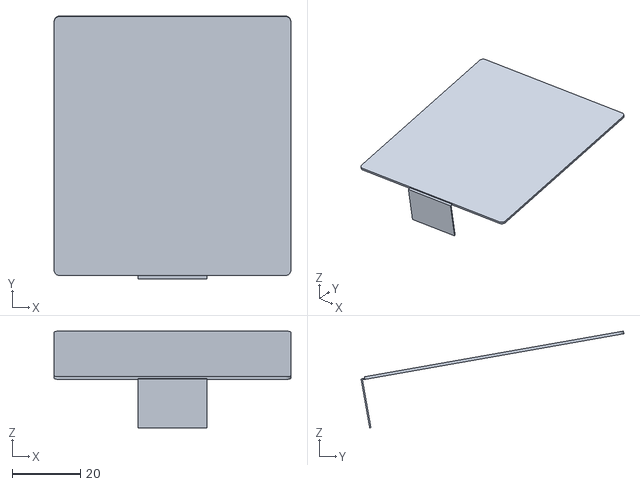
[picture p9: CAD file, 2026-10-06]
case/stl/fitcheck/keypad.stl
69.2 x 76.9 x 28.3

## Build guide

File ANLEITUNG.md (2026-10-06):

# Mini Casino: Anzeige und Guthaben auf RFID

**V11: Das LCD ist durch ein 1,3"-OLED (I2C) ersetzt, die LEDs sind entfallen.** Verdrahtung, Pins und Fehlersuche stehen in [UMBAU_OLED.md](UMBAU_OLED.md). Die Abschnitte zu LCD und LEDs unten sind damit überholt.

**Aktuell V10: Die Guthaben liegen im EEPROM des Uno, nicht mehr auf der Karte. Einmal kurz auflegen, danach beliebig viele Runden nur mit den Tasten. Der Kartenspeicher wird nicht mehr gelesen oder beschrieben.** Tasten, Regeln und offene Runden: [SPIELPLAN_V8.md](SPIELPLAN_V8.md). Aktueller Tonanschluss und Jackpot: [SOUND_V9.md](SOUND_V9.md). Die V6-Erstaufladung und UID-Merkliste bleiben erhalten.

Der Sketch `MiniCasino/MiniCasino.ino` zeigt seine Ergebnisse auf dem LCD. Zur
Fehlersuche ist aktuell zusätzlich `DEBUG_LOG = true` mit **115200 Baud** aktiviert;
ein geöffneter serieller Monitor ist nicht zum Betrieb erforderlich. Er ist
für euren klassischen Arduino Uno (ATmega328P), RC522 und das **QAPASS 1602A**
mit 16 Pins und 16×2 Zeichen ausgelegt. Der separate LCD-Test wurde mit der
unten dokumentierten Pinbelegung von euch erfolgreich durchgeführt.

## Bauteile und belegte Pins

| Bauteil | Anzahl / Ausführung |
|---|---|
| Arduino Uno | 1, ATmega328P |
| Breadboards | 2 |
| LCD | 1, QAPASS 1602A ohne I2C-Adapter |
| RFID-Reader | 1, RC522, Firmware 0x88 bei eurem Modul |
| Potentiometer | 1, 10 kΩ, für LCD-Kontrast |
| Widerstand | 1, 200 Ω, für LCD-Hintergrundbeleuchtung |
| Transponder | Eigene MIFARE-Classic- und Ultralight-kompatible Projekt-Tags |
| Verbindungsmaterial | Jumperkabel, USB-Kabel, für die RC522-Eingänge passende Pegelwandlung |

Ab V11: **A4/A5** sind der I2C-Bus des OLED, **D9–D13** gehören dem Reader.
**A0–A2** sind Tastereingänge, **D2** ist der Buzzer. **D3–D8** und **A3** sind frei. D0/D1 werden vom Sketch nicht
genutzt; diese Pins gehören beim Uno auch zur seriellen Upload-Verbindung.
Die beiden Geräte verwenden unterschiedliche Signalpins und gemeinsame Masse.

## LCD anschließen (bis V10, überholt)

Vor dem Umstecken USB/Stromversorgung trennen. Nach den Anschlussbeschriftungen
gehen: Die Nummerierung nicht von der Betrachtungsrichtung erraten.

| LCD-Pin | Beschriftung | Verbindung |
|---|---|---|
| 1 | VSS / GND | Arduino GND |
| 2 | VDD / VCC | Arduino 5V |
| 3 | VO / V0 | Mittlerer Anschluss eines 10-kOhm-Potentiometers |
| 4 | RS | Arduino D8 |
| 5 | RW / R/W | GND |
| 6 | E / Enable | Arduino D7 |
| 7–10 | D0–D3 | Nicht anschließen |
| 11 | D4 | Arduino D6 |
| 12 | D5 | Arduino D5 |
| 13 | D6 | Arduino D4 |
| 14 | D7 | Arduino D3 |
| 15 | A / LED+ | Über euren 200-Ohm-Widerstand an 5V |
| 16 | K / LED- | GND |

Die äußeren Potentiometeranschlüsse kommen an 5V und GND. Am Potentiometer drehen,
bis die Schrift sichtbar ist. Ein beleuchtetes Display oder schwarze Kästchen
allein bedeuten noch nicht, dass die Datenverbindung funktioniert. Ohne Poti
kann VO für einen ersten Test direkt an GND liegen; der Kontrast ist dann maximal
und je nach Modul zu stark. Den Pin nicht offen lassen.

Im Code bedeutet `LiquidCrystal lcd(8, 7, 6, 5, 4, 3)` die Arduino-Pinfolge
RS, E, LCD-D4, LCD-D5, LCD-D6, LCD-D7. Nicht die physischen LCD-Pinnummern!

## RC522

Die funktionierende Signalbelegung bleibt:

| RC522 | Arduino Uno |
|---|---|
| 3.3V | 3.3V, nicht 5V |
| GND | GND |
| SDA / SS | D10 |
| RST | D9 |
| MOSI | D11 |
| MISO | D12 |
| SCK | D13 |
| IRQ | Frei |

Der RC522 arbeitet mit 3,3-V-Logik. Für die Uno-Ausgänge SS, RST, MOSI und SCK
einen für SPI geeigneten 5V-auf-3,3V-Pegelwandler verwenden. Das LCD nutzt 5V.
5V und 3,3V dürfen nicht dieselbe Versorgungsschiene speisen. Alle verwendeten
GND-Schienen mit Arduino GND verbinden. Bei zwei Breadboards auch mögliche
Unterbrechungen der Versorgungsschienen beachten.

## Hochladen und testen

1. `MiniCasino/MiniCasino.ino` in der Arduino IDE öffnen. Hauptprogramm und
   LCD-Test sind getrennte Sketches: nicht in dieselbe Datei oder als zusätzliche
   IDE-Tabs zusammenkopieren, sonst wären `setup()` und `loop()` doppelt vorhanden.
2. Bibliotheken: keine. OLED- und RC522-Treiber liegen im Sketch-Ordner.
3. Arduino Uno und dessen Port auswählen, mit dem Upload-Pfeil hochladen.
4. Das OLED sollte `Mini Casino v11` / `Karte auflegen` zeigen.
5. Einen eigenen leeren Projekt-Transponder auflegen und während des Schreibens
   liegen lassen. Erwartet: `Neu aufgeladen!` / `100 Pkt`.
6. Transponder entfernen und erneut auflegen. Erwartet: `Guthaben:` / `100 Pkt`.
7. Arduino aus- und wieder einschalten, dieselbe Karte auflegen. Weiterhin 100:
   Der Wert liegt dauerhaft auf dem Transponder.
8. Eine zweite leere Karte erhält ihr eigenes Startguthaben von 100.

Das Ergebnis bleibt fünf Sekunden sichtbar, danach erscheint wieder die
Aufforderung zum Auflegen. Für einen neuen Scan die Karte kurz entfernen.

## Was gespeichert wird

Unterstützt werden MIFARE Classic Mini/1K/4K mit Key A `FF FF FF FF FF FF`
oder dem öffentlichen NDEF-Key A `D3 F7 D3 F7 D3 F7`, sowie Ultralight-kompatible Tags mit frei les-/schreibbaren
Seiten 4–7. Die Anzeige `MIFARE Ultralight or Ultralight C` identifiziert das
genaue Modell nicht. Geschützte Ultralight-C-Karten werden nicht entsperrt;
3DES-Authentifizierung ist nicht implementiert. Euer Reader-Clone mit
Firmwareversion 0x88 wird akzeptiert.

- **Classic:** Guthaben in Datenblock 4, Sektor 1. Zur Erstbelegung müssen
  Block 4 Nullbytes oder eine freigegebene leere NDEF-Struktur enthalten;
  ohne NDEF-Struktur müssen die Datenblöcke 5 und 6 vollständig `00` enthalten.
  Endet ein erkannter leerer NDEF-Strom bereits in Block 4, dürfen Block 5/6
  Restdaten enthalten und bleiben unverändert. Geschrieben wird nur
  Block 4. Block 0 (Herstellerdaten) und Block 7 (Schlüssel/Zugriffsrechte)
  werden nicht beschrieben.
- **Ultralight:** Guthaben auf den vier Seiten 4–7, jeweils vier Bytes. Zur
  Erstbelegung müssen diese 16 Bytes vollständig `00` enthalten oder eine der
  unten beschriebenen leeren NDEF-Strukturen bilden. Seiten 0–3 und spätere
  Konfigurations-/Sperrseiten werden nicht beschrieben.

"Leer" bezieht sich auf diese festgelegten Projektbereiche, nicht auf den
gesamten Transponder. Andere Speicherbereiche werden nicht auf Leerheit geprüft.
Ein Tag mit tatsächlichen NDEF-Nutzdaten oder unbekannter Struktur wird weiter
als belegt abgelehnt. Fremde aktive Nutzdaten werden nicht automatisch gelöscht.

### Leere NFC-Tools-Tags (Ultralight ab v2, Classic ab v3)

Bei Ultralight-kompatiblen Tags und Classic erkennt `EmptyRegion.h` zusätzlich exakt:

- `03 00 FE`: NDEF-TLV ohne Nachricht.
- `03 03 D0 00 00 FE`: einzelner leerer NDEF-Record.
- `03 04 D8 00 00 00 FE`: einzelner leerer NDEF-Record mit leerem ID-Längenfeld.

Die Struktur muss am Anfang des gelesenen Bereichs stehen. `FE` beendet den
NDEF-TLV-Strom; nachfolgende Bytes sind keine aktive NDEF-Nutzlast. Innerhalb
der Seiten 4–7 (Classic: Block 4) werden auch solche Restbytes bei der Übernahme ersetzt. Das
betrifft den im Nutzerlog beobachteten Tag mit dem Rest `6E 30 34 3A ...`.
Andere Records/TLVs, fehlende Abschlussmarker und nichtleere Nutzdaten bleiben
gesperrt. Dies ist eine begrenzte Erkennung, kein allgemeiner NDEF-Parser.

Bei Ultralight wird vor der NDEF-Übernahme Seite 3 gelesen: Der Capability-Container muss
Type-2-Mapping-Version 1, mindestens 16 Nutzbytes und freien Lese-/Schreibzugriff
angeben. Physische Sperrbits können trotzdem einen späteren Schreibfehler
verursachen. Es werden keine Sperren aufgehoben. Vor jedem Initialisieren muss
außerdem eine zweite Lesung dieselben 16 Ausgangsbytes liefern.

Danach liegt dort das eigene MCAS-Format; NFC Tools zeigt dessen Guthaben nicht
als normalen NDEF-Datensatz an. Nicht erneut mit NFC Tools löschen, wenn das
Guthaben erhalten bleiben soll. Mit `LEERE_NDEF_TAGS_NUTZEN = false` lässt sich
die NDEF-Übernahme abschalten. Bei Classic gilt die strenge Nullbyte-Regel für
die Nachbarblöcke 5 und 6 nur ohne erkannte leere NDEF-Struktur in Block 4.
Ab v4 werden Restdaten hinter dem bereits in Block 4 liegenden Abschlussmarker
in den Nachbarblöcken akzeptiert und unverändert belassen. Dort wird kein Type-2-Capability-
Container gelesen; die erfolgreiche Sektoranmeldung ist Voraussetzung.

Bei einem fehlgeschlagenen Classic-Standardkey-Versuch wird die Karte neu
ausgewählt und ihre UID/SAK geprüft, bevor der öffentliche NDEF-Key versucht
wird. Ein Kartenwechsel bricht den Vorgang ab. Die Anmeldung ändert keine
Schlüssel/Zugriffsrechte und garantiert noch keine Schreibberechtigung.

| Byteposition, ab 0 | Inhalt | Zweck |
|---|---|---|
| 0–3 | ASCII `MCAS` | Kennung des Casino-Datensatzes |
| 4 | `01` | Formatversion |
| 5–8 | `uint32_t`, niedrigstes Byte zuerst | Ganze Spielpunkte, 0 bis 4.294.967.295 |
| 9–13 | Fünf Nullbytes | Reserviert; müssen für Version 1 Null sein |
| 14–15 | CRC-16, niedrigstes Byte zuerst | Prüfsumme über Bytes 0–13 |

Die CRC-16/CCITT-FALSE verwendet Startwert `0xFFFF`, Polynom `0x1021`,
keine Bitspiegelung und kein abschließendes XOR. 100 Punkte stehen in den
Guthabenbytes als `64 00 00 00` (hexadezimal).

Beim bloßen Einlesen wird ein gültiges abgeschlossenes Guthaben angezeigt; erst ein Tastendruck startet eine neue kostenpflichtige Spielrunde.
Auch 0 Punkte gelten als gültiger Stand und erzeugen keine neue Aufladung.
V7 ergänzt das Farbspiel mit Einsatzabzug und Gewinnauszahlung; die Erstaufladung bleibt einmalig pro UID. Die Spielpunkte haben keinen Manipulationsschutz.

Die UID wird außerdem in der dauerhaften EEPROM-Merkliste registriert. Vor
jeder Erstaufladung muss sie dort unbekannt und ein Platz verfügbar sein.
Reservierung, Datenformat, Übernahme vorhandener Karten und Grenzen stehen in
[UidRegistry.h](MiniCasino/UidRegistry.h). Der Wert auf der Karte bleibt die Quelle des Guthabens.

## Erstaufladung und vorhandene Funktionen

V7 ergänzt diesen Ablauf durch GameRuntime.h und die Tastenabfrage. Eine gültige
offene Runde wird vor der normalen Guthabenanzeige abgeschlossen. Das LCD zeigt
bei Spielbereitschaft `10 Pkt: S/R/G`. Details: [SPIELPLAN_V8.md](SPIELPLAN_V8.md).

1. `setup()` startet LCD, EEPROM-Liste, SPI und Reader. Der Clone 0x88 wird akzeptiert.
2. `loop()` fragt Karten ab; `erkennungsfehler()` zählt Fehler und steuert die
   seltenere LCD-Meldung. `logLebenszeichen()` gibt alle fünf Sekunden Status aus.
3. `bearbeiteKarte()` prüft den Typ und meldet Classic über `meldeClassicAn()` an.
4. `leseSpeicher()` liest gültige Daten mit begrenzten Wiederholungen.
   `waehleDieselbeKarte()` und `erneuereSitzung()` verhindern Schreiben auf eine
   während einer Wiederholung ausgetauschte Karte.
5. `leseGuthaben()` validiert Kennung, Version, reservierte Bytes und CRC.
   Gültige Guthaben werden angezeigt; `UidRegistry::reserve()` und `confirm()`
   übernehmen eine vorhandene Karte in die Liste, ohne Kartendaten zu ändern.
6. Bei fehlendem gültigem Guthaben prüft `UidRegistry::find()` die UID.
   Bekannte/reservierte UIDs erhalten keine erneute Erstaufladung.
7. Für eine unbekannte UID folgen Leerheitsprüfung und erneutes Lesen der
   Ausgangsdaten. Erst nach dauerhafter Reservierung darf geschrieben werden.
8. `erstelleGuthaben()` erzeugt den Datensatz mit den Funktionen in `CardRecord.h`. `speichern()`
   führt höchstens drei Versuche aus; `schreibeStartguthaben()` schreibt Classic-
   Block 4 bzw. Ultralight-Seiten 5, 6, 7 und zuletzt 4. Identisches Rücklesen aller
   16 Bytes ist Voraussetzung für `Neu aufgeladen!` und Bestätigung der Reservierung.
9. `zeigeGuthaben()` und `meldung()` beschriften das LCD. Nach fünf Sekunden
   erscheint wieder `Karte auflegen`. Die Kartenkommunikation wird beendet.

Die Reservierung bleibt nach unklarer Speicherung bestehen. Erneutes Auflegen
liest den tatsächlichen Stand, löst aber keine zweite Aufladung aus. Eine
Teilschreibung kann deshalb manuelle Klärung erfordern. Es gibt keine automatische
Reparatur oder Rücksetzung der Liste.

## Einstellungen

| Einstellung | Wert | Zweck |
|---|---|---|
| `STARTGUTHABEN` | 100 | Nur für neue, unbekannte UIDs mit leerem Projektbereich |
| `DEBUG_LOG` | true | Zusätzlicher Diagnose-Log; LCD funktioniert auch ohne Konsole |
| `LOG_BAUD` | 115200 | Muss der Einstellung des seriellen Monitors entsprechen |
| `LEERE_NDEF_TAGS_NUTZEN` | true | Beschriebene leere NFC-Tools-Strukturen übernehmen |
| `MAX_VERSUCHE` | 3 | Begrenzte Lese- und Schreibwiederholungen |
| `SCAN_PAUSE_MS` | 1000 | Pause nach einem Erkennungsversuch mit Antwort |
| `ANZEIGEDAUER_MS` | 5000 | Ergebnisanzeige |

Die bestätigte Pinbelegung bleibt erhalten. Alle Dateien aus `MiniCasino`
zusammen übernehmen, die Treiber `OledText.h` und `Rc522.h` eingeschlossen.
EEPROM kommt mit dem Arduino-Core, OLED- und RC522-Treiber liegen
im Ordner. Nachinstalliert werden muss nichts. Ein geöffneter
serieller Monitor ist nicht zum Betrieb erforderlich.

## Meldungen und Diagnose

`Guthaben:` zeigt einen bereits gültigen Stand; `Neu aufgeladen!` bestätigt eine
neue, zurückgelesene Speicherung. `Schon aufgeladen` und `Aufladung offen` sind
Sperren gegen erneutes Startguthaben. `UID-Liste voll` oder `UID-Liste Fehler`
verhindern neue Aufladungen. `Karte ruhig` erscheint erst nach mehreren
Erkennungsfehlern. Speicher-, Anmelde- und NDEF-Fehler bleiben sichtbar.

Alle Logkennungen und die Baudrate sind in [LOG_ANLEITUNG.md](LOG_ANLEITUNG.md)
beschrieben; Bedienfälle und Prüfstand in [TESTPLAN.md](TESTPLAN.md).

## Quellen

- [Arduino LiquidCrystal HelloWorld](https://github.com/arduino-libraries/LiquidCrystal/blob/master/examples/HelloWorld/HelloWorld.ino)
- [Arduino EEPROM](https://github.com/arduino/ArduinoCore-avr/blob/master/libraries/EEPROM/README.md)
- [MFRC522 API und Speicherbefehle](https://github.com/miguelbalboa/rfid/blob/master/src/MFRC522.cpp)
- [NXP MIFARE Ultralight C](https://www.nxp.com/docs/en/data-sheet/MF0ICU2.pdf)

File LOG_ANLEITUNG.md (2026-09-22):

# Diagnose V9

Die Bedienung erfolgt am LCD. DEBUG_LOG aktiviert zusätzlich die serielle
Ausgabe. Ein geöffneter Monitor ist nicht zum Betrieb erforderlich.

## Sauberen Log aufnehmen

1. Ganzen Sketch-Ordner mit allen sieben Header-Dateien laden.
2. Monitor auf **115200 Baud** stellen, alte Ausgabe leeren und RESET drücken.
3. Erwartet: Mini Casino v10, EINMAL PRO UID, UID-LISTE bereit und Firmware=0x88.
4. Fünf Sekunden ohne Karte warten, dann einen einzelnen Tag ruhig auflegen.
5. Den Abschnitt SCAN bis ENDE einschließlich UID-LISTE betrachten.

V9 meldet nach einer abgeschlossenen Buchung und dem Lauflicht zusätzlich
`SOUND | WIN: Level-up.`, `SOUND | LOSS: Womp-womp.` oder
`SOUND | JACKPOT: Fanfare + 8-Bit-Abschluss.`. JACKPOT gilt nur für einen
Gewinn auf Grün mit 90 Punkten Auszahlung. In Tonmodus 0 gibt es kein SOUND-Log.

Euer letzter Log mischt alte v4-Ausgaben mit 9600 Baud, Neustarts und unlesbare
Zeichen. Eine falsche Monitor-Baudrate kann diese Zeichen erklären. V9 benötigt
115200. BOOT nach Upload, RESET oder Öffnen des Monitors ist erklärbar. Ohne
solche Aktionen wären ungeplante Neustarts beziehungsweise Versorgung zu prüfen.

## Kennungen

| Kennung | Bedeutung |
|---|---|
| BOOT / MODUS | Version, Betriebsart und Millisekunden seit Start |
| UID-LISTE | EEPROM bereit, UID registriert/reserviert oder Sperrgrund |
| RFID | Reader-Firmware; 0x88 ist euer Clone |
| LIVE | Abfragen, REQA-Timeouts, Scans, Erkennungsfehler und Firmware alle fünf Sekunden |
| SCAN | Anfrage mit anderer Antwort als Timeout; noch kein erfolgreicher Scan |
| REQA / ATQA | Status der Anfrage / Antwortbytes |
| SELECT UID / UID | Auswahlstatus / Kennung der ausgewählten Karte |
| RF RECOVERY | Antennenfeld nach mehreren Fehlern kurz neu gestartet |
| TYPE / AUTH | Kartentyp / Classic-Anmeldung mit Standard- oder öffentlichem NDEF-Key |
| RETRY WAKE / RETRY SELECT | Neue Sitzung mit derselben UID; Kartenwechsel wird abgelehnt |
| READ / READ RETRY / DATA 16 Bytes | Lesen, Wiederholungsversuch, fehlerfrei gelesene Nutzbytes |
| FORMAT / BELEGT / NDEF / NDEF REST | Formatprüfung und Leerheitsentscheidung |
| PRECHECK | Ausgangsdaten nicht stabil lesbar; kein Schreiben |
| WRITE VERSUCH / WRITE Soll-Daten / WRITE | Versuch, gewünschte Daten und Schreibstatus |
| VERIFY | Nur „Alle 16 Bytes stimmen“ bestätigt die Speicherung durch Rücklesen |
| GUTHABEN / LCD | Vorhandener oder bestätigter neuer Stand / angezeigte Textzeilen |
| KONTO | Konto geladen, neu angelegt, gesperrt abgewiesen oder als unklar gemeldet |
| SPIEL | Auflösung mit Wahl, Ergebnis, Auszahlung und neuem Guthaben |
| SITZUNG | Sitzung beendet: Zeit abgelaufen oder von Hand über Rot halten |
| TON | Lautstärkestufe laut/leise/aus und ob sie im EEPROM gespeichert wurde |
| EINSATZ | Einsatz geändert, gespeichert oder wegen zu wenig Guthaben gekürzt |
| NACHLADEN / EEPROM | Konten aufgefüllt / gesamter EEPROM-Bereich gelöscht |
| HALT / ENDE | Abschluss; zum erneuten Lesen Karte entfernen und auflegen |

## Funkqualität beurteilen

`REQA | Status=3 (Timeout)` heißt **keine Karte im Feld** und ist der Normalfall.
`Status=1 (Error in communication.)` ist etwas anderes: da antwortet eine Karte,
aber zu schwach für eine saubere Übertragung. Viele solcher Zeilen bedeuten ein
Reichweiten- oder Versorgungsproblem, kein Software-Problem.

Seit V10 gegengesteuert wird so:

- **Volle Empfangsverstärkung** (48 dB statt 33 dB). Der Start meldet
  `RFID | Antennengewinn=0x70`.
- **Drei schnelle Versuche je Durchlauf** statt einem. Ein einzelner Funkfehler
  übersieht keine aufliegende Karte mehr.
- **WUPA statt REQA.** Damit wird auch eine Karte erkannt, die nach dem letzten
  Lesen angehalten wurde und einfach liegen geblieben ist.
- **Nach einem Funkfehler nur 120 ms Pause** statt einer vollen Sekunde. Die
  Sekunde gilt nur noch nach einer erfolgreich gelesenen Karte.

Bleibt es trotzdem zäh, ist es Hardware: siehe Versorgung und Verkabelung in
[ANLEITUNG.md](ANLEITUNG.md).

REQA-Timeouts sind ohne neue Karte und bei angehaltenen Karten normal. Sie sind
**keine Funkfehlerquote**. Erkennungsfehler zählt unerwartete REQA-/SELECT-Fehler;
READ-/WRITE-Fehler stehen separat im Log. Einzelne Erkennungsfehler ändern das
LCD nicht. Erst eine Serie führt zur Felderholung und gegebenenfalls zum Hinweis
Karte ruhig / auflegen. Alle Datenprüfungen bleiben aktiv.

## Eine Runde im Log

Nur das erste Auflegen erzeugt überhaupt RFID-Zeilen. Danach laufen Runden ohne
Karte und erzeugen je genau eine Zeile:

```text
SCAN 1 ... SELECT UID ... UID | DF 51 AA 39
KONTO | Bekannte UID; Guthaben aus dem EEPROM geladen.
GUTHABEN | Vorhanden: 100
SPIEL | Wahl=ROT Ergebnis=ROT Einsatz=10 Auszahlung=20 Guthaben=110
SPIEL | Wahl=GRUEN Ergebnis=SCHWARZ Einsatz=10 Auszahlung=0 Guthaben=100
SITZUNG | Zeit abgelaufen. Zum Weiterspielen Karte erneut kurz auflegen.
```

Es gibt keine READ-, WRITE- oder VERIFY-Zeilen mehr: der Kartenspeicher wird
nicht angefasst. Die frühere Classic-Anmeldung (`AUTH`) entfällt ebenfalls.

`SPIEL | EEPROM-Buchung nicht bestaetigt.` heißt, dass die Runde nicht gilt und
der alte Stand unverändert steht. `KONTO | UID bekannt, aber kein lesbares
Konto.` deutet auf einen abgebrochenen allerersten Buchungsversuch hin; das
nächste Auflegen holt die Erstgutschrift nach.

## Einmaliges Startguthaben erkennen

Schon aufgeladene Karten: **UID dauerhaft registriert** und **GUTHABEN | Vorhanden**,
ohne WRITE. Erst nach erfolgreicher Registrierung schützt die Liste eine UID
auch nach Löschen der Karte. Bei neuer leerer Karte muss vor WRITE die dauerhafte
Reservierung stehen. VERIFY bestätigt die Speicherung. Bei unklarem Ausgang
bleibt die Reservierung bestehen; spätere Scans dürfen lesen, aber keine zweite
Erstaufladung beginnen. Liste voll/Fehler bedeutet, dass Registrierung scheiterte.

## Verbleibende Funkfehler

Ihr habt inzwischen das Aufladen aller Karten bestätigt. Die genaue Ursache
der zuvor beobachteten CRC-, Kollisions- und Auswahlfehler steht weiter nicht
fest. Ein Anmeldefehler beweist auch keinen fehlenden Schlüssel.

Einen einzelnen Tag ruhig dicht auflegen, Smartphone und andere Tags entfernen,
kurze feste Leitungen und 3,3-V-Versorgung prüfen; vor Umstecken ausschalten.
Siehe [MFRC522-Fehlersuche](https://github.com/miguelbalboa/rfid#troubleshooting).
Alle Regeln und Grenzen der Liste: [UidRegistry.h](MiniCasino/UidRegistry.h).

## Spiel-Logzeilen in V7

| Kennung | Bedeutung |
|---|---|
| SPIELSTART | Frischer Tastendruck, Einsatz 10, Ergebnis einmalig festgelegt |
| EINSATZ | Abgezogener Einsatz und festes Ergebnis als offene Runde bestätigt |
| SPIEL | Nach bestätigtem Endstand: Wahl, Ergebnis, Einsatz, Auszahlung, Guthaben |
| RUNDE OFFEN | Zielwerte bleiben fest; gleiche Karte erneut auflegen oder Taste drücken |
| RECOVER | Gültige offene Runde auf Karte erkannt; kein neuer Einsatz/keine neue Ziehung |

Das WRITE/Rücklesen-Protokoll gilt sowohl für Erstaufladung als auch für
Spielbuchungen. Beim bloßen Lesen einer abgeschlossenen Karte gibt es weiterhin
kein WRITE. Bei einer offenen Runde kann bereits das Auflegen deren ausstehende
Auszahlung abschließen. Ein bestätigter Gewinn steht erst nach VERIFY im Log.

Im Hexdump einer offenen Runde stehen auch die Ergebnisbytes. Der Diagnosemodus
ist transparent und kein manipulationsgeschützter Casinobetrieb.

## Lauflicht in V8

Die SPIEL-Zeile bestätigt den gebuchten Endstand vor der LED-Animation.
Während der ungefähr fünf Sekunden werden keine weiteren Spiele angenommen.
Neue Ziehungen verwenden Schwarz/Rot/Grün mit 45/45/10 Prozent.

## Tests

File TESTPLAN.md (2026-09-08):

# Prüfung V8

Aktueller Build: Uno kompiliert/gelinkt, 20.172 Byte Programm und 465 Byte
statischer RAM. Zusätzlich bestehen die Tests für alle 100 gewichteten Lose,
alle neun Start-/Zielkombinationen des Lauflichts, zunehmende Wartezeiten und
das passende letzte Licht. Die bisherigen Karten-, UID- und Tastentests bestehen.
Grün zahlt nun 90 aus; Tests prüfen neue Version-3-Runden und die weiterhin
20 auszahlenden alten Version-2-Runden. Der LED-Aufbau ist noch nicht auf Hardware geprüft.

Aktuelle Beispiele: 100 Startpunkte → Schwarz/Rot gewonnen: 110, Grün gewonnen:
180, verloren: 90. Bei Einsatz des letzten Guthabens von 10 → Grün gewonnen: 90.
Die weiter unten dokumentierten V7-Grün-Auszahlungen gelten nur für alte Runden.

Am Aufbau: jede LED am vorgesehenen Pin mit eigenem Vorwiderstand, passende
Endfarbe, kein Folgespiel durch Halten, Guthaben unverändert nach Reset während
der Animation. Neue Verteilung: Schwarz 45 %, Rot 45 %, Grün 10 %; keine Garantie
für entsprechende Häufigkeiten in einer kurzen Testserie.

## Weitergeltende Tests / dokumentierter V7-Prüfstand

# Testplan V7

Vom Nutzer bestätigt: LCD, Reader-Firmware 0x88 und inzwischen Aufladung aller
verwendeten Transponder. V7 ist lokal für den Uno kompiliert und gelinkt,
aber noch nicht hochgeladen oder am Aufbau geprüft.

## Am Aufbau prüfen

Den ganzen Ordner MiniCasino laden. Monitor: **115200 Baud**.

| Fall | Erwartung |
|---|---|
| Ohne Karte starten | BOOT v7, UID-LISTE bereit, Karte auflegen, LIVE alle fünf Sekunden |
| Aufgeladene Karte erstmals mit V7 lesen | Guthaben unverändert; UID dauerhaft registriert; keine WRITE-Zeile |
| Dieselbe Karte erneut lesen, auch nach Reset | Guthaben unverändert; keine WRITE-Zeile |
| Gültige Testkarte mit 0 oder 42 Punkten | Vorhandenen Stand anzeigen, keine Aufladung auf 100 |
| Neue UID, freigegebener leerer Bereich | Reservierung, WRITE, VERIFY, 100 Punkte |
| Registrierte UID mit anschließend gelöschtem Kartenbereich | Schon aufgeladen / Keine Neuauflad.; kein WRITE |
| Abgebrochene Erstaufladung | Reservierung bleibt; nächster Scan liest gültigen Stand oder meldet Aufladung offen |
| Unbekannte UID mit fremden aktiven Daten | Speicher belegt; kein WRITE |
| Classic: Nullbytes in Block 4, Daten in Block 5/6 | Sektor belegt; kein WRITE |
| Anmeldung oder READ fehlgeschlagen | Fehlermeldung; keine Aufladung auf Verdacht |
| Einzelner REQA-/SELECT-Fehler | Logeintrag; LCD bleibt unverändert |
| Drei Erkennungsfehler mit höchstens fünf Sekunden Abstand | RF RECOVERY; einmaliger Hinweis, sobald keine Ergebnisanzeige läuft |
| Keine neue Karte oder bereits angehaltene Karte | REQA-Timeouts ohne LCD-Fehlermeldung |
| DEBUG_LOG false | LCD bleibt funktionsfähig; keine serielle Ausgabe |

Lösch-/Abbruchfälle nur mit entbehrlichen eigenen Testkarten prüfen. Die Liste
stellt verlorenes Guthaben nicht wieder her und gibt reservierte UIDs nicht
automatisch frei. Das gilt auch bei noch intakter leerer NDEF-Struktur nach Abbruch.

## Automatisierte Prüfungen

`python pruefen.py` kompiliert Hauptsketch, Bibliotheken und Core und linkt für
den Uno. Zusätzlich prüfen 27 static_assert-Fälle in empty_region_test.cpp die
tatsächliche Leerheits-/NDEF-/CC-Erkennung. Sechs Szenarien in uid_registry_test.cpp
führen die Registry-Methoden mit einem EEPROM-Modell aus: Reservierung,
Bestätigung, Neustart, keine weiteren EEPROM-Schreibzugriffe bei Wiederholung,
UID-Längen, volle Liste ohne Verdrängung, unbekannte Daten, beschädigter Eintrag,
unterbrochener Commit und werkseitig gelöschter Speicher.

Die Registry-Tests nutzen C++14 zur Compilezeit-Ausführung; das Produktionsprogramm
bleibt C++11. Sie simulieren keine Funkübertragung oder sämtliche elektrischen
Folgen einer instabilen Versorgung. V7 muss nach Upload am Aufbau geprüft werden.

## Zusätzliche Spieltests V7

| Aktion | Erwartung |
|---|---|
| Karte mit 100 lesen, Taste drücken, Verlust | Karte enthält 90 |
| Karte mit 100 lesen, Taste drücken, Treffer | Karte enthält 110: 10 Einsatz, 20 Auszahlung |
| 10 Punkte, Verlust / Gewinn | 0 / 20 Punkte |
| Weniger als 10 Punkte | Zu wenig Punkte; kein WRITE |
| Taste beim Start oder lange während/nach Spiel halten | Keine automatischen Folgerunden |
| Zwei Tasten gemeinsam drücken | Keine Runde; erst alle loslassen |
| Karte nach Lesen entfernen, Taste drücken | Kein Einsatz ohne bestätigte gleiche Karte |
| Andere UID vor einer Spielbuchung auflegen | Kein Schreiben auf die andere UID |
| Funkunterbrechung während Runde, gleiche Karte erneut auflegen | Gleiche Zielwerte; keine erneute Ziehung/kein zusätzlicher Einsatz |
| Andere Karte während offener Runde | Keine neue Runde; zuerst offene Runde abschließen |
| Neustart mit gültigem offenem V2-Datensatz auf Karte | RECOVER beendet dieselbe Runde |
| Gültiger abgeschlossener Endstand, erneut auflegen | Keine erneute Auszahlung |
| Beschädigter V2-Datensatz nach Reset | Gesperrt; keine neue Startaufladung |

Gezielte Abbruchtests nur auf entbehrlichen Testkarten. Bei beschädigter
Mehrseiten-Schreibung plus Reset kann automatische Wiederherstellung unmöglich
sein. Eine physische Kartenverbindung wurde durch die lokalen Tests nicht simuliert.

`tests/game_test.cpp` prüft zusätzlich Gewinn/Verlust, Unterdeckung/Überlauf,
gleiche Regeln für alle Farben, V6-Formatkompatibilität, offenen Gewinn/Verlust,
beschädigte Datensätze, Tasterprellen, Gedrückthalten, Mehrfachtasten und millis-
Überlauf. Die Methoden werden tatsächlich zur Compilezeit ausgeführt.

Alle drei Builds wurden erfolgreich kompiliert/gelinkt: ohne Ton, passives
Piezo-Modul und aktiver Buzzer. Standard ohne Ton: 19.620 Byte Programmspeicher,
461 Byte statischer RAM. Stack/Laufzeitspitzen sind darin nicht enthalten.
Das ist keine Bestätigung der Kompatibilität des noch unbekannten Tonmoduls.

## Tonintegration V9

Der Hauptsketch schaltet Ton standardmäßig für einen passiven Buzzer ein.
`python pruefen.py` übernimmt diese Einstellung aus der Hauptdatei; die
Optionen `--sound 0` und `--sound 2` prüfen die alternativen Modi.

`tests/sound_test.cpp` prüft zur Compilezeit gültige Tonhöhen, positive
Notendauern, eine maximale Jingle-Dauer von drei Sekunden und die Zuordnung
von Gewinn, Verlust und Jackpot. Die vorhandenen Karten-, Registry- und
Spieltests laufen mit. Der Standardbuild belegt 22.190 Byte Flash und
488 Byte statischen RAM, der aktive Buzzer-Modus 20.676 Byte und 471 Byte.
Alle drei Tonmodi wurden erfolgreich kompiliert und gelinkt. Ton aus belegt
20.246 Byte Flash und 465 Byte statischen RAM.
Stack und Laufzeitspitzen sind nicht enthalten. Kein Upload oder Hörtest
wurde von Codex durchgeführt.

Am echten Aufbau noch prüfen:

| Aktion | Erwartung |
|---|---|
| Runde starten | Ein kurzer Tick je LED-Wechsel; Abstände werden länger |
| Schwarz/Rot gewonnen | Level-up nach bestätigter Auszahlung |
| Verloren, auch bei grünem Ergebnis und falscher Wahl | Womp-womp, kein Jackpot |
| Grün gewählt und gewonnen | JACKPOT! GRUEN und Fanfare; netto +80 |
| Taste während des Jingles halten | Keine zusätzliche Runde; erst loslassen |
| Funkfehler vor bestätigter Buchung | Kein Ergebnis-Jingle für unbestätigte Auszahlung |

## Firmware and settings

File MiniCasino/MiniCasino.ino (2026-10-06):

/*
 * Mini Casino - Konten im EEPROM, Karte als Ausweis, Ausgabe auf 1,3"-OLED
 *
 * Hardware: Arduino Uno (ATmega328P), RC522, 128x64-OLED mit I2C (4 Pins).
 * OLED: GND->GND, VCC->5V, SCL->A5, SDA->A4. Mehr Leitungen gibt es nicht.
 * RC522: SS/SDA->D10, RST->D9, MOSI->D11, MISO->D12, SCK->D13, VCC->3.3V.
 * Vollstaendige Stromversorgung/Pegelwandlung: siehe ../ANLEITUNG.md.
 *
 * Ablauf:
 * 1. Karte kurz auflegen. Erkannt wird nur die UID.
 * 2. Konto im EEPROM suchen; unbekannte UID einmalig mit 100 Punkten anlegen.
 * 3. Sitzung laeuft ohne Karte: Farbe druecken, so lange und so oft gewuenscht.
 * 4. Jede Runde wird in einer EEPROM-Buchung verrechnet und zurueckgelesen.
 * 5. Nach SITZUNG_MS ohne Tastendruck endet die Sitzung; Karte neu auflegen.
 *
 * Der Kartenspeicher wird NICHT mehr gelesen oder beschrieben. Es gibt keine
 * Classic-Anmeldung, keine Leerheits-/NDEF-Pruefung und keinen Schreibvorgang.
 * Jede Karte taugt als Ausweis, auch eine voll belegte.
 * Speicher: EEPROM-Format 07, 16 Byte Header + 32 Byte je Konto, 31 Konten.
 * Jedes Konto haelt zwei Kopien mit eigener CRC; geschrieben wird abwechselnd,
 * damit ein Stromausfall waehrend einer Buchung nie ein Konto zerstoert.
 * V10: Guthaben im EEPROM statt auf der Karte. Einmal kurz auflegen genuegt.
 * V9: Farbspiel mit Tasten A0/A1/A2, 10 Punkten Einsatz und Buzzer-Sounds.
 * Einmaliges Startguthaben pro UID. Die alte Merkliste (Format 06) wird nicht
 * uebernommen und nicht ueberschrieben: siehe CASINO_EEPROM_LOESCHEN.
 * Auszahlung Schwarz/Rot 20, Gruen 90, Verlust 0. Chancen: 45/45/10 Prozent.
 * Keine LEDs mehr: das Lauflicht laeuft auf dem OLED.
 * Tasten: 4x4-Folientastatur an D3-D8, A0, A1. 1/2/3 setzen auf Schwarz/Rot/Gruen,
 * A Einsatz eintippen, B abmelden, C Ton, D Hilfe. Details: GameRuntime.h.
 * Spielplan/Taster: ../SPIELPLAN_V8.md; Ton D2: ../SOUND_V9.md. Kein FORCE.
 * Guthaben sind ganze Spielpunkte, kein manipulationsgeschuetztes Bezahlsystem.
 * Bibliotheken: nur EEPROM aus dem Arduino Core. Display-Treiber und
 * Schrift (CC0) liegen in OledText.h, es muss nichts installiert werden.
 * Der RC522 laeuft ueber einen eigenen kleinen Treiber (Rc522.h) statt der
 * MFRC522-Bibliothek; er liest nur die UID.
 */

// Ton ist eingeschaltet. 1 = passiver Buzzer (Melodien), 2 = aktiver Buzzer
// (nur Piepsrhythmus), 0 = aus. Der Modultyp ist bisher nicht bestaetigt.
// D2 -> 330 Ohm -> S; Minus -> GND; unbekannten mittleren Pin offen lassen.
#ifndef CASINO_SOUND_MODE
#define CASINO_SOUND_MODE 1
#endif

// Nachlade-Modus: nur voruebergehend einschalten, wenn alle Punkte verspielt
// sind. 1 = beim Start jedes bekannte Konto unter STARTGUTHABEN auf
// STARTGUTHABEN anheben. Es wird nichts geloescht und keine Karte beschrieben.
// Danach zurueck auf 0 setzen und neu hochladen, sonst fuellt jeder Neustart
// alle Konten wieder auf.
#ifndef CASINO_NACHLADEN
#define CASINO_NACHLADEN 0
#endif

// ACHTUNG, unwiderruflich: 1 verwirft beim Start den gesamten EEPROM-Bereich,
// also ALLE UIDs UND ALLE GUTHABEN. Genau einmal noetig beim Wechsel von der
// alten Merkliste (Format 06) auf die Konten (Format 07), weil vorhandene
// Fremddaten nie automatisch ueberschrieben werden. Sofort danach wieder auf 0
// setzen und neu hochladen.
#ifndef CASINO_EEPROM_LOESCHEN
#define CASINO_EEPROM_LOESCHEN 0
#endif

// Waehrung auf dem Display. 1 = Euro-Zeichen, 0 = "Pkt".
// Die Schrift kennt kein Euro-Zeichen; es ist in OledText.h selbst gezeichnet
// und liegt auf Code 0. Am Spiel aendert das nichts, es sind weiterhin
// reine Spielpunkte ohne jeden Gegenwert.
#ifndef CASINO_EURO
#define CASINO_EURO 1
#endif

// Display-Chip. Fast alle 1,3-Zoll-OLEDs haben einen SH1106 (0), die
// 0,96-Zoll-Module meist einen SSD1306 (1). Ist das Bild um zwei Pixel
// verschoben oder steht am Rand Pixelmuell, auf die andere Einstellung gehen.
#ifndef CASINO_OLED_SSD1306
#define CASINO_OLED_SSD1306 0
#endif

// Simulationsbetrieb ohne RC522 (z.B. Wokwi). 1 = statt des Readers stehen
// vier Taster an D9 bis D12 fuer vier Karten. Sonst ist alles identisch:
// gleiche Pins, gleiches Spiel, gleicher EEPROM, gleiche Verwaltung.
#ifndef CASINO_SIM
#define CASINO_SIM 0
#endif

#include <Arduino.h>
#include "Rc522.h"
#include <EEPROM.h>
#include <string.h>
#include "OledText.h"
#include "UidRegistry.h"
#include "GameRules.h"
// EmptyRegion.h und CardRecord.h gehoeren nicht mehr zum Sketch: Guthaben
// liegen im EEPROM, der Kartenspeicher wird nicht mehr angefasst. Die Dateien
// und ihre Tests bleiben als Beleg fuer das alte Kartenformat liegen.

void spielMenue();

// OLED am Hardware-I2C des Uno: SDA = A4, SCL = A5. Kein Reset-Pin.
// Wokwi kennt nur den SSD1306, deshalb gilt der in der Simulation immer.
OledText anzeige;
Rc522 rfid;   // SS D10, RST D9, SPI D11-D13.
Casino::UidRegistry<EEPROMClass> uidListe(EEPROM);

const uint32_t STARTGUTHABEN = 100;  // Ganze Spielpunkte.
// Diagnose-Log auf der seriellen Schnittstelle. Mit false werden die Texte gar
// nicht erst mitkompiliert (rund 3 KB). Euer Uno hat einen 4-KB-Bootloader und
// damit nur 28 KB fuer den Sketch; mit true sind es rund 21 KB, das passt auch.
const bool DEBUG_LOG = false;
const unsigned long LOG_BAUD = 115200UL;
const unsigned long ANZEIGEDAUER_MS = 5000UL;
const unsigned long SCAN_PAUSE_MS = 1000UL;   // Nach erfolgreich gelesener Karte.
// Nach einem Funkfehler darf es sofort weitergehen: eine Sekunde Zwangspause
// fuehlt sich an, als wuerde die Karte gar nicht erkannt.
const unsigned long FEHLER_PAUSE_MS = 120UL;
const byte SCAN_VERSUCHE = 3;  // Schnelle Wiederholungen je Durchlauf.
// Nach so langer Tastenruhe endet die Sitzung. Sonst koennte jemand anderes
// einfach weiterdruecken und das Guthaben des letzten Spielers verbrauchen.
const unsigned long SITZUNG_MS = 60000UL;
// Diese Zustandswerte liegen im Arduino-RAM; das Guthaben liegt im EEPROM.
bool readerBereit = false;
bool ergebnisSichtbar = false;
unsigned long ergebnisSeit = 0;
unsigned long letzterLog = 0;
unsigned long letzteAbfrage = 0;
unsigned long naechsterScanSeit = 0;
bool scanPause = false;
unsigned long scanPauseDauer = SCAN_PAUSE_MS;
unsigned long scanNummer = 0;
unsigned long abfragen = 0;
unsigned long keineAntwort = 0;
unsigned long funkfehler = 0;
unsigned long letzterFunkfehler = 0;
byte fehlerFolge = 0;
bool funkHinweisGezeigt = false;

void logKopf(const __FlashStringHelper *thema) {
  if (!DEBUG_LOG) return;
  Serial.print('[');
  Serial.print(millis());
  Serial.print(F(" ms] "));
  Serial.print(thema);
  Serial.print(F(" | "));
}

void logText(const __FlashStringHelper *thema, const __FlashStringHelper *text) {
  if (!DEBUG_LOG) return;
  logKopf(thema);
  Serial.println(text);
}

void logHex(byte wert) {
  if (!DEBUG_LOG) return;
  if (wert < 0x10) Serial.print('0');
  Serial.print(wert, HEX);
}

void logBytes(const __FlashStringHelper *thema, const byte *daten, byte anzahl) {
  if (!DEBUG_LOG) return;
  logKopf(thema);
  for (byte i = 0; i < anzahl; ++i) {
    if (i) Serial.print(' ');
    logHex(daten[i]);
  }
  Serial.println();
}

// Status: 0 OK, 1 Timeout, 2 Fehler, 3 Kollision (siehe Rc522.h).
void logStatus(const __FlashStringHelper *schritt, byte status) {
  if (!DEBUG_LOG) return;
  logKopf(schritt);
  Serial.print(F("Status="));
  Serial.println(status);
}
// Lebenszeichen ohne Logflut: Timeouts bei REQA sind ohne neue Karte normal.
void logLebenszeichen() {
  if (!DEBUG_LOG || millis() - letzterLog < 5000UL) return;
  letzterLog = millis();
  logKopf(F("LIVE"));
  Serial.print(F("ReaderBereit="));
  Serial.print(readerBereit);
  Serial.print(F(" Abfragen="));
  Serial.print(abfragen);
  Serial.print(F(" REQA-Timeouts="));
  Serial.print(keineAntwort);
  Serial.print(F(" Scans="));
  Serial.print(scanNummer);
  Serial.print(F(" Erkennungsfehler="));
  Serial.print(funkfehler);
  Serial.print(F(" Firmware=0x"));
  logHex(rfid.version());
  Serial.println();
}

// Zwei kurze Zeilen aus dem Flash ausgeben. Texte passen in 16 Zeichen.
void meldung(const __FlashStringHelper *oben,
             const __FlashStringHelper *unten) {
  anzeige.setCursor(0, 0);
  anzeige.print(oben);
  for (byte i = strlen_P((PGM_P)oben); i < 16; ++i) anzeige.print(' ');
  anzeige.setCursor(0, 1);
  anzeige.print(unten);
  for (byte i = strlen_P((PGM_P)unten); i < 16; ++i) anzeige.print(' ');
  anzeige.hinweis(nullptr);   // Jeder Bildschirm setzt seinen Hinweis selbst.
  if (DEBUG_LOG) {
    logKopf(F("LCD"));
    Serial.print(oben);
    Serial.print(F(" / "));
    Serial.println(unten);
  }
}

// Bereitschaft anzeigen, ohne die Karte oder ihr Guthaben zu veraendern.
void startAnzeige() {
  spielMenue();
  ergebnisSichtbar = false;
}

// Einzelne Erkennungsfehler nur protokollieren. Erst eine Serie meldet das LCD.
// REQA-Timeouts ohne neue Karte werden hier bewusst nicht mitgezaehlt.
void erkennungsfehler() {
  ++funkfehler;
  if (millis() - letzterFunkfehler > 5000UL) {
    fehlerFolge = 0;
    funkHinweisGezeigt = false;
  }
  letzterFunkfehler = millis();
  if (fehlerFolge < 249) ++fehlerFolge;
  else fehlerFolge = 3;
  if (fehlerFolge % 3 == 0) {
    logText(F("RF RECOVERY"), F("Drei weitere Erkennungsfehler; Antennenfeld kurz neu starten."));
    rfid.antenne(false);
    delay(20);
    rfid.antenne(true);
    delay(20);
  }
  if (fehlerFolge >= 3 && !funkHinweisGezeigt && !ergebnisSichtbar) {
    meldung(F("Karte ruhig"), F("auflegen"));
    funkHinweisGezeigt = true;
    ergebnisSeit = millis();
    ergebnisSichtbar = true;
  }
}
// Waehrung anhaengen und die belegten Stellen zurueckgeben.
byte lcdWaehrung() {
#if CASINO_EURO
  anzeige.write((uint8_t)0);   // Direkt an die Zahl, ohne Leerzeichen: 250<euro>
  return 1;
#else
  anzeige.print(F(" Pkt"));
  return 4;
#endif
}

// Bis zu zehn Ziffern plus Waehrung passen auch beim groessten uint32_t aufs LCD.
void zeigeGuthaben(uint32_t guthaben, bool neu) {
  meldung(neu ? F("Neu aufgeladen!") : F("Guthaben:"), F(""));
  anzeige.setCursor(0, 1);
  anzeige.print((unsigned long)guthaben);
  lcdWaehrung();
  if (DEBUG_LOG) {
    logKopf(F("GUTHABEN"));
    Serial.print(neu ? F("Neu gespeichert und geprueft: ") : F("Vorhanden: "));
    Serial.println((unsigned long)guthaben);
  }
}

#include "GameRuntime.h"
void bearbeiteKarte(); // Wird auch vom CARD-Befehl der Verwaltung genutzt.

// Eine UID in den Leser legen, als haette er sie gerade erkannt.
void legeKarteAuf(const byte *uid, byte laenge) {
  rfid.uid.size = laenge;
  for (byte i = 0; i < laenge; ++i) rfid.uid.uidByte[i] = uid[i];
  // 4 Byte: MIFARE Classic 1K, 7 Byte: Ultralight. Beides akzeptiert der Sketch.
  rfid.uid.sak = laenge == 4 ? 0x08 : 0x00;
  logBytes(F("UID"), rfid.uid.uidByte, rfid.uid.size);
  bearbeiteKarte();
}
#include "AdminSerial.h"

// Verarbeitet genau die durch rfid.auswaehlen() ausgewaehlte Karte.
// Ab Format 07 liegt das Guthaben im EEPROM des Uno. Der Kartenspeicher wird
// weder gelesen noch beschrieben: es gibt keine Classic-Anmeldung, keine
// Leerheits-/NDEF-Pruefung und keinen Schreibvorgang mehr. Die Karte dient nur
// noch als Ausweis fuer ihre UID, deshalb reicht kurzes Auflegen.
// Das Anhalten der Karte erfolgt anschliessend zentral in loop().
void bearbeiteKarte() {
  const Rc522::Uid erwartet = rfid.uid;
  if (DEBUG_LOG) {
    logKopf(F("TYPE"));
    Serial.print(F("SAK=0x"));
    logHex(rfid.uid.sak);
    Serial.println();
  }
  int slot = uidListe.find(erwartet.uidByte, erwartet.size);
  if (slot == -2) {
    logText(F("UID-LISTE"), F("EEPROM ungueltig/nicht bereit. Kein Konto nutzbar."));
    meldung(F("UID-Liste Fehler"), F("Siehe Log"));
    return;
  }
  // Gesperrte Karte: gar nichts tun, auch keine Sitzung starten.
  if (slot >= 0 && uidListe.banned(slot)) {
    logText(F("KONTO"), F("Karte ist gesperrt. Keine Sitzung, kein Zugriff aufs Guthaben."));
    meldung(F("Karte gesperrt"), F("Siehe Admin"));
    return;
  }
  bool neuesKonto = false;
  if (slot == -1) {
    // Reservierung muss lesbar sein, BEVOR ein Startguthaben gilt.
    slot = uidListe.reserve(erwartet.uidByte, erwartet.size);
    if (slot < 0) {
      logText(F("UID-LISTE"), F("Keine Reservierung moeglich; Liste voll oder ungueltig."));
      meldung(slot == -3 ? F("UID-Liste voll") : F("UID-Liste Fehler"), F("Nicht aufgeladen"));
      return;
    }
    if (!uidListe.confirm(slot)) {
      logText(F("UID-LISTE"), F("Eintrag nicht bestaetigt. Karte erneut auflegen."));
      meldung(F("Aufladung offen"), F("Siehe Log"));
      return;
    }
    neuesKonto = true;
    logText(F("UID-LISTE"), F("Neue UID dauerhaft registriert."));
  }
  if (!uidListe.funded(slot)) {
    // Ohne lesbare Kontokopie wurde nie ein Startguthaben gebucht. Das
    // Nachholen ist deshalb kein zweites Startguthaben fuer dieselbe UID.
    if (!uidListe.setBalance(slot, STARTGUTHABEN)) {
      logText(F("KONTO"), F("Erstgutschrift nicht bestaetigt. Karte erneut auflegen."));
      meldung(F("Aufladung offen"), F("Siehe Log"));
      return;
    }
    logText(F("KONTO"), neuesKonto ? F("Einmaliges Startguthaben gutgeschrieben.")
                                   : F("Offene Erstgutschrift nachgeholt."));
    neuesKonto = true;
  }
  uint32_t guthaben = uidListe.balance(slot);
  if (!neuesKonto) logText(F("KONTO"), F("Bekannte UID; Guthaben aus dem EEPROM geladen."));
  zeigeGuthaben(guthaben, neuesKonto);
  starteSitzung(erwartet, slot, guthaben);
}


// Einmal nach Einschalten/Reset: LCD und Reader starten, Standardschluessel setzen.
#if CASINO_SIM
// Kartenleser-Ersatz: vier Taster gegen GND, auf den Pins des RC522.
// Jeder steht fest fuer eine Karte, zwei Classic und zwei Ultralight.
const byte SIM_PINS[4] = {9, 10, 11, 12};
const byte SIM_LEN[4] = {4, 4, 7, 7};
const byte SIM_UIDS[4][7] = {
  {0xDF, 0x51, 0xAA, 0x39, 0x00, 0x00, 0x00},
  {0x08, 0x85, 0xB1, 0xA8, 0x00, 0x00, 0x00},
  {0x04, 0x9F, 0x90, 0x5C, 0x11, 0x01, 0x89},
  {0x04, 0xCA, 0xBD, 0x5C, 0x11, 0x01, 0x89}
};
byte simGedrueckt = 0;
unsigned long simEntprellt = 0;

void simSetup() {
  for (byte i = 0; i < 4; ++i) pinMode(SIM_PINS[i], INPUT_PULLUP);
}
// Nur die neu hinzugekommene Taste zaehlt, wie ein einzelnes Auflegen.
void simService() {
  byte maske = 0;
  for (byte i = 0; i < 4; ++i)
    if (digitalRead(SIM_PINS[i]) == LOW) maske |= (byte)(1 << i);
  if (maske == simGedrueckt) return;
  if (millis() - simEntprellt < 40UL) return;
  simEntprellt = millis();
  byte neu = (byte)(maske & ~simGedrueckt);
  simGedrueckt = maske;
  for (byte i = 0; i < 4; ++i) {
    if (!(neu & (byte)(1 << i))) continue;
    legeKarteAuf(SIM_UIDS[i], SIM_LEN[i]);
    ergebnisSeit = millis();
    ergebnisSichtbar = true;
    return;   // Immer nur eine Karte gleichzeitig.
  }
}
#endif

void setup() {
  // Immer starten: darueber laeuft auch das Verwaltungsprotokoll (AdminSerial.h).
  Serial.begin(LOG_BAUD);
  if (DEBUG_LOG) {
    Serial.println();
    logText(F("BOOT"), F("Mini Casino v11 | 115200 Baud | OLED I2C A4/A5"));
    logText(F("MODUS"), F("Konten im EEPROM. Karte nur als Ausweis, Spiel ueber Tasten."));
    logText(F("BOOT"), F("Wiederholtes BOOT im laufenden Betrieb: Reset/Versorgung pruefen."));
  }
  spielSetup();
  anzeige.begin();
#if CASINO_EEPROM_LOESCHEN
  uidListe.wipe();
  logText(F("EEPROM"), F("GELOESCHT: alle UIDs UND alle Guthaben verworfen."));
  logText(F("EEPROM"), F("Sofort CASINO_EEPROM_LOESCHEN auf 0 setzen und neu hochladen."));
#endif
  bool listeBereit = uidListe.begin();
  logText(F("UID-LISTE"), listeBereit ? F("Bereit: Uno fuehrt bis zu 31 Konten dauerhaft.")
                                      : F("EEPROM unbekannt/fremd. Konten gesperrt; siehe CASINO_EEPROM_LOESCHEN."));
#if CASINO_NACHLADEN
  if (listeBereit) {
    int aufgefuellt = 0;
    for (int slot = 0; slot < uidListe.capacity(); ++slot) {
      if (uidListe.funded(slot) && uidListe.balance(slot) < STARTGUTHABEN
          && uidListe.setBalance(slot, STARTGUTHABEN)) ++aufgefuellt;
    }
    if (DEBUG_LOG) {
      logKopf(F("NACHLADEN"));
      Serial.print(F("Konten auf Startguthaben angehoben: "));
      Serial.println(aufgefuellt);
    }
    logText(F("NACHLADEN"), F("Danach CASINO_NACHLADEN auf 0 setzen und neu hochladen."));
  }
#endif
  uint8_t tonOpt = listeBereit ? uidListe.options() : 0;
  tonStufe = (tonOpt & 1) ? TON_AUS : ((tonOpt & 2) ? TON_LEISE : TON_LAUT);
  if (TON_MODUS && DEBUG_LOG) {
    logKopf(F("TON"));
    Serial.print(stufenName(tonStufe));
    Serial.println(F(" | Taste C schaltet weiter: laut, leise, aus."));
  }
#if CASINO_SIM
  simSetup();
  readerBereit = true;
  logText(F("SIM"), F("Ohne RC522. Taster D9-D12 stehen fuer vier Karten."));
  meldung(F("Mini Casino v11"), F("Karte auflegen"));
  startAnzeige();
  return;
#endif
  meldung(F("Mini Casino"), F("Starte Reader..."));
  rfid.begin();   // Mit voller Empfangsverstaerkung fuer die Clone-Antennen.
  byte version = rfid.version();
  if (DEBUG_LOG) {
    logKopf(F("RFID"));
    Serial.print(F("Firmware=0x"));
    logHex(version);
    Serial.println();
  }
  if (version == 0x00 || version == 0xFF) {
    meldung(F("RFID fehlt"), F("Kabel pruefen"));
    return;
  }
  readerBereit = true; // Auch euer Clone mit Version 0x88 wird akzeptiert.
  startAnzeige();
}

// Wiederholt Karten abfragen. millis()-Differenz funktioniert auch beim Ueberlauf.
// Eine Sekunde Scan-Abstand verhindert schnelle Fehler-/LCD-Wiederholungen.
void loop() {
  anzeige.hinweisAktualisieren();
  adminService(); // Verwaltungsbefehle haben nie Vorrang vor dem Spiel.
  unsigned long jetzt = millis();
  // Jede Taste hat eine feste Funktion (GameRuntime.h). Im Durchlauf mit
  // einem Tastendruck wird nicht nach Karten gesucht. Bewusst unabhaengig vom
  // Reader: ohne RC522 (Simulation, defektes Modul) bleiben Tasten, LCD und
  // das Verwaltungsprotokoll trotzdem bedienbar.
  if (tastenService(jetzt)) return;
  logLebenszeichen();
  if (spielAktiv && millis() - sitzungSeit >= SITZUNG_MS) beendeSitzung(false);
  if (!readerBereit) return;
  if (ergebnisSichtbar && millis() - ergebnisSeit >= ANZEIGEDAUER_MS) startAnzeige();
#if CASINO_SIM
  simService();   // Kein Funk: die Karten kommen von den Tastern.
  return;
#endif
  if (scanPause && millis() - naechsterScanSeit < scanPauseDauer) return;
  scanPause = false;
  if (millis() - letzteAbfrage < 100UL) return;
  letzteAbfrage = millis();

  // Mehrere schnelle Versuche pro Durchlauf. Ein einzelner Funkfehler darf
  // nicht dazu fuehren, dass eine aufliegende Karte uebersehen wird.
  // WUPA statt REQA: das weckt auch eine Karte, die nach dem letzten Lesen
  // angehalten wurde und einfach liegen geblieben ist.
  byte status = Rc522::TIMEOUT;
  byte auswahl = Rc522::FEHLER;
  for (byte versuch = 0; versuch < SCAN_VERSUCHE; ++versuch) {
    status = rfid.wecken();
    ++abfragen;
    if (status == Rc522::OK || status == Rc522::KOLLISION) {
      auswahl = rfid.auswaehlen(); // Sofort, vor allen Logs zur Anfrage.
      if (auswahl == Rc522::OK) break;
    }
    // Gar keine Antwort heisst: da liegt nichts. Nicht weiter probieren.
    if (status == Rc522::TIMEOUT) break;
    delay(8);
  }
  if (status == Rc522::TIMEOUT) {
    ++keineAntwort; // Keine Karte im Feld: normal, keine Pause.
    return;
  }
  // Nach einem Fehler nur kurz warten, nach einer gelesenen Karte laenger.
  scanPause = true;
  scanPauseDauer = (auswahl == Rc522::OK) ? SCAN_PAUSE_MS : FEHLER_PAUSE_MS;
  naechsterScanSeit = millis();
  ++scanNummer;
  if (DEBUG_LOG) {
    logKopf(F("SCAN"));
    Serial.println(scanNummer);
  }
  logStatus(F("WUPA"), status);
  if (status != Rc522::OK && status != Rc522::KOLLISION) {
    erkennungsfehler();
    return;
  }
  logStatus(F("SELECT UID"), auswahl);
  if (auswahl != Rc522::OK) {
    erkennungsfehler();
    return;
  }
  logBytes(F("UID"), rfid.uid.uidByte, rfid.uid.size);
  fehlerFolge = 0;
  funkHinweisGezeigt = false;

  // Liegt die Karte der laufenden Sitzung noch auf, nur die Sitzung frisch
  // halten. Sonst wuerde WUPA sie im Sekundentakt neu anmelden.
  bool neueKarte = !(spielAktiv && rfid.uid.size == spielUid.size
      && memcmp(rfid.uid.uidByte, spielUid.uidByte, rfid.uid.size) == 0);
  if (neueKarte) bearbeiteKarte();
  else sitzungSeit = millis();
  // Auf jedem Verarbeitungspfad aufraeumen, auch nach Fehlern.
  rfid.anhalten();
  logText(F("ENDE"), F("Karte kann weg. Gespielt wird ueber die Tasten."));
  naechsterScanSeit = millis();
  scanPauseDauer = SCAN_PAUSE_MS;
  // Nur eine neu verarbeitete Karte zeigt ein Ergebnis an. Die liegen gebliebene
  // Karte der Sitzung darf Einsatz-Eingabe oder Hilfe nicht unterbrechen.
  if (neueKarte) {
    ergebnisSeit = millis();
    ergebnisSichtbar = true;
  }
}

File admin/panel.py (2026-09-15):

"""Web-Adminpanel fuer das Mini Casino.

Startet einen kleinen Webserver und spricht ueber die serielle Schnittstelle mit
dem Uno (Protokoll siehe MiniCasino/AdminSerial.h).

    python admin/panel.py                      # Port wird gesucht, http://127.0.0.1:8080
    python admin/panel.py --serial COM6
    python admin/panel.py --host 0.0.0.0       # im Netz erreichbar, siehe Warnung

Laeuft mit der Standardbibliothek, auf Windows wie auf dem Raspberry Pi.
pyserial wird benutzt, wenn es installiert ist, ist aber nicht noetig.

Wichtig: Das Oeffnen der Schnittstelle loest beim Uno einen Reset aus. Die
Guthaben liegen im EEPROM und ueberstehen das; eine laufende Sitzung nicht.
"""
from __future__ import annotations

import argparse
import collections
import json
import os
import socket
import sys
import threading
import time
from http.server import BaseHTTPRequestHandler, ThreadingHTTPServer

BAUD = 115200
RESET_WARTEN = 2.5   # Nach dem Oeffnen laeuft der Bootloader.
ANTWORT_TIMEOUT = 4.0


# --------------------------------------------------------------------------
# Serielle Schnittstelle: pyserial, sonst Win32 per ctypes, sonst POSIX.
# --------------------------------------------------------------------------
class SerialBase:
    def write(self, data: bytes) -> None: raise NotImplementedError
    def read(self, n: int) -> bytes: raise NotImplementedError
    def close(self) -> None: raise NotImplementedError


class PySerialPort(SerialBase):
    def __init__(self, port: str):
        import serial
        self._s = serial.Serial(port, BAUD, timeout=0.05)

    def write(self, data): self._s.write(data)
    def read(self, n): return self._s.read(n)
    def close(self): self._s.close()


class WindowsSerialPort(SerialBase):
    """Minimaler Ersatz fuer pyserial ueber die Win32-API."""

    def __init__(self, port: str):
        import ctypes
        from ctypes import wintypes as w
        self._ct = ctypes
        self._k32 = ctypes.WinDLL("kernel32", use_last_error=True)

        class DCB(ctypes.Structure):
            _fields_ = [
                ("DCBlength", w.DWORD), ("BaudRate", w.DWORD), ("flags", w.DWORD),
                ("wReserved", w.WORD), ("XonLim", w.WORD), ("XoffLim", w.WORD),
                ("ByteSize", ctypes.c_byte), ("Parity", ctypes.c_byte),
                ("StopBits", ctypes.c_byte), ("XonChar", ctypes.c_char),
                ("XoffChar", ctypes.c_char), ("ErrorChar", ctypes.c_char),
                ("EofChar", ctypes.c_char), ("EvtChar", ctypes.c_char),
                ("wReserved1", w.WORD),
            ]

        class TIMEOUTS(ctypes.Structure):
            _fields_ = [("ReadIntervalTimeout", w.DWORD),
                        ("ReadTotalTimeoutMultiplier", w.DWORD),
                        ("ReadTotalTimeoutConstant", w.DWORD),
                        ("WriteTotalTimeoutMultiplier", w.DWORD),
                        ("WriteTotalTimeoutConstant", w.DWORD)]

        handle = self._k32.CreateFileW(
            f"\\\\.\\{port}", 0x80000000 | 0x40000000, 0, None, 3, 0, None)
        if handle == ctypes.c_void_p(-1).value:
            raise OSError(f"COM-Port {port} laesst sich nicht oeffnen "
                          f"(Fehler {ctypes.get_last_error()}). "
                          f"Laeuft noch ein serieller Monitor?")
        self._h = w.HANDLE(handle)

        dcb = DCB()
        dcb.DCBlength = ctypes.sizeof(DCB)
        if not self._k32.GetCommState(self._h, ctypes.byref(dcb)):
            raise OSError("GetCommState fehlgeschlagen")
        dcb.BaudRate = BAUD
        dcb.ByteSize = 8
        dcb.Parity = 0
        dcb.StopBits = 0
        # fBinary | fDtrControl=enable | fRtsControl=enable
        dcb.flags = 0x01 | (1 << 4) | (1 << 12)
        if not self._k32.SetCommState(self._h, ctypes.byref(dcb)):
            raise OSError("SetCommState fehlgeschlagen")

        t = TIMEOUTS(0, 0, 50, 0, 200)
        self._k32.SetCommTimeouts(self._h, ctypes.byref(t))

    def write(self, data):
        from ctypes import wintypes as w
        geschrieben = w.DWORD(0)
        self._k32.WriteFile(self._h, data, len(data),
                            self._ct.byref(geschrieben), None)

    def read(self, n):
        from ctypes import wintypes as w
        puffer = (self._ct.c_char * n)()
        gelesen = w.DWORD(0)
        if not self._k32.ReadFile(self._h, puffer, n,
                                  self._ct.byref(gelesen), None):
            return b""
        return bytes(puffer[:gelesen.value])

    def close(self):
        self._k32.CloseHandle(self._h)


class PosixSerialPort(SerialBase):
    """Fuer den Raspberry Pi: rohes tty ueber termios."""

    def __init__(self, port: str):
        import termios
        self._fd = os.open(port, os.O_RDWR | os.O_NOCTTY | os.O_NONBLOCK)
        attrs = termios.tcgetattr(self._fd)
        iflag, oflag, cflag, lflag, ispeed, ospeed, cc = attrs
        geschwindigkeit = getattr(termios, f"B{BAUD}")
        iflag = 0
        oflag = 0
        lflag = 0
        cflag = termios.CS8 | termios.CREAD | termios.CLOCAL
        cc = list(cc)
        cc[termios.VMIN] = 0
        cc[termios.VTIME] = 0
        termios.tcsetattr(self._fd, termios.TCSANOW,
                          [iflag, oflag, cflag, lflag,
                           geschwindigkeit, geschwindigkeit, cc])

    def write(self, data): os.write(self._fd, data)

    def read(self, n):
        try:
            return os.read(self._fd, n)
        except BlockingIOError:
            return b""
        except OSError:
            return b""

    def close(self): os.close(self._fd)


def port_oeffnen(port: str) -> SerialBase:
    try:
        import serial  # noqa: F401
        return PySerialPort(port)
    except ImportError:
        pass
    if os.name == "nt":
        return WindowsSerialPort(port)
    return PosixSerialPort(port)


def port_suchen() -> str | None:
    """Ersten plausiblen Anschluss finden."""
    if os.name == "nt":
        import winreg
        try:
            with winreg.OpenKey(winreg.HKEY_LOCAL_MACHINE,
                                r"HARDWARE\DEVICEMAP\SERIALCOMM") as key:
                gefunden = []
                for i in range(winreg.QueryInfoKey(key)[1]):
                    name, wert, _ = winreg.EnumValue(key, i)
                    # USB-Anschluesse zuerst: der Uno meldet sich als usbser.
                    gefunden.append((0 if "USB" in name.upper() else 1, wert))
                gefunden.sort()
                return gefunden[0][1] if gefunden else None
        except OSError:
            return None
    import glob
    treffer = sorted(glob.glob("/dev/ttyACM*") + glob.glob("/dev/ttyUSB*"))
    return treffer[0] if treffer else None
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

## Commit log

2026-09-01 lcd test sketch for the qapass 1602a
    shows a running counter so the wiring on d3 to d8 can be checked before the real sketch goes on the uno.
2026-09-01 first sketch: read the card, show the balance and give new cards 100 points
    mifare classic and ultralight, the balance lives on the card with a crc. serial diagnostics at 9600 baud, lcd on 8,7,6,5,4,3 and the rc522 on spi.
2026-09-08 v6: remember every uid in the eeprom so the starting balance is paid only once
    reserve the slot before writing, confirm after the readback and never evict an entry. the tests run the registry against an eeprom model at compile time.
2026-09-08 v7: colour game with three buttons and a 10 point stake
    game rules, card records for open rounds, debounced buttons and the round flow on the uno. black, red or green, a hit pays double the stake.
2026-09-08 v7 game plan: rules, button wiring and the pin budget
2026-09-08 v8 game plan: led chase on a3 to a5, green is rarer and pays 9x
    45/45/10 odds, the chase slows down and stops on the drawn colour. the booking is confirmed before the animation runs.
2026-09-08 buzzer test sketch on d2
    [Ton_Test.ino]
2026-09-08 v9: buzzer jingles for win, loss and jackpot
    short arcade style tone sequences in flash, played only after the booking is confirmed. a tick on every led step.
2026-09-15 wiring guide for the lcd, the rc522 and the card format
2026-09-15 serial admin protocol and a web admin panel
    ping, list, set, stake, flag, free, sound, card and wipe over the same serial port. panel.py serves a small web ui with the python stdlib and runs on windows and the raspberry pi. the bat file starts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
2026-09-15 v10: balances live in the uno eeprom, the card is only an id
    tap the card once, then play with the buttons for as long as you like. every account keeps two crc protected copies so a power cut never destroys it. hold black to change the stake, hold red to log o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
2026-09-15 wokwi simulation without any hardware
    build_sim.py bundles the sketch into one header for wokwi, four buttons on d9 to d12 stand in for the cards. the generated wokwi folder is ignored.
2026-09-22 short readme with animated pastel graphics and a remade wiring diagram
    banner, how it works strip and the wiring as svg with css and smil animations, github plays them straight from the readme. docs/make_graphics.py generates all three. the long readme is gone, the german docs stay for the details.
2026-09-22 3d printable console: parametric case with stl files, fit check parts and a dimensioned layout
    two parts, body and top plate tilted by 10 degrees. arcade buttons, leds, lcd window, rc522 frame and buzzer grille sit in the lid, uno standoffs, breadboard pocket and the usb and dc jack cutouts in the body. case/make_case.py builds everything with manifold3d and every size is a parameter. layout.svg is the dimension drawing, the fitcheck stls are dummy parts for the slicer.
    [assembly.stl, base.stl, breadboard.stl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]
2026-09-22 local 3d viewer with the game built in
    case/viewer/index.html opens straight from the folder, no server and no artifact. dark studio look with edge lines so the parts read well, calmer lights. the model plays: tap zone and cards start a session, the buttons on the model bet, holding black ramps the stake, red logs out, green cycles the volume. leds, lcd, buzzer jingles and the serial log follow GameRuntime.h. make_case.py now also writes viewer/models.js, three.js r128 is bundled under its mit license.
2026-09-22 detailed electronics, wires, transponders and the admin panel in the 3d viewer
    uno with headers and silkscreen, half breadboard with its hole grid, resistors and the contrast pot, lcd and rc522 modules with pin headers, microswitches under the arcade buttons, 44 jumper wires as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
    [assembly.stl, lid.stl]
2026-10-06 v11: oled, 4x4 keypad and own small drivers instead of libraries
    - 1.3" i2c oled (sh1106/ssd1306) replaces the 16x2 lcd, own driver with
    the cc0 chroma48 font, title bar and a hint line for the keys
    - leds removed, the spin runs on the oled
    - 4x4 membrane keypad: 1/2/3 bet on black/red/green, a types the stake
    directly, b logs out with a question, c sound, d help
    - own rc522 driver, hand clocked buzzer, xorshift random and a leaner
    admin protocol: 26.9 kb -> 17.9 kb flash, no library to install
    - keypad pin mapping and oled verified on the hardware; the new rc522
    driver is not tested on hardware yet
    - hardware test sketch, wokwi diagram, build script and docs updated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
    [GameRuntime.h, Hardware_Test.ino, MiniCasino.ino]
2026-10-06 v11 live preview: new 3d viewer, case, schematics, graphics and license
    - new offline 3d viewer on three.js r147: photoreal uno, oled, rc522,
    keypad, breadboard, buzzer, wires per net, explode, x-ray, build guide
    - firmware simulation with a pixel-exact oled, keypad, sounds and the
    admin protocol, plus tools to extract and check the firmware data
    - case redesigned for v11: oled window, keypad recess and slot, rfid tap
    zone, buzzer grille, new fit-check parts and stl files
    - new schematic, wiring, pinout, banner and how-it-works svgs in light
    and dark, readme and umbau doc updated
    - mini casino attribution license, credits link felixthedev.com and
    derfacn.com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
    [assembly.stl, base.stl, breadboard.stl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]
2026-11-10 presentation: 10 minute lf7 talk as pptx and web deck
    praesentation/ holds the talk for felix and nikita: 16 slides with speaker
    notes and timing, as a powerpoint file with 3d stills and as a web deck that
    embeds case/viewer live (camera presets, a real round with a big oled mirror)
    and ends in an animated low-poly casino city.
    case/viewer/js/app.js exposes the oled texture as app.oledTex so the web
    deck can mirror the display.
